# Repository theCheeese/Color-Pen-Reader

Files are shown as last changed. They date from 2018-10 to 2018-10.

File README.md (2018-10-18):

# Color-Pen-Reader
This is an open-source pen reader for dyslexic and visually impaired people that is able to read text written in any color on any colored background, started at NYIT for 2018's Senior Design course.

# Setup

To set this project up, you will have to buy all the parts listed, assemble everything together and make all the right physical connections according to the docs listed in the Final Senior Design Proposal pdf in the Proposals folder.

The software setup is done by first expanding the Raspi filesystem in raspi-config, then removing any extraneous programs the stock Raspi came with like Libreoffice and Wolfram Alpha, and then running the setup script in the ColorPenReader folder. If you have around 5-6 GB free on the SD card though, you can just run the setup script as is and not worry about storage space. The setup script installs all the required dependencies, tesseract-ocr, festival, virtualenv, pip, modifies the .profile file to accomodate the changes, and compiles OpenCV 3.4.1 on the Raspi.

If the setup script encounters issues with compiling OpenCV, refer to https://www.pyimagesearch.com/2017/09/04/raspbian-stretch-install-opencv-3-python-on-your-raspberry-pi/ for a tutorial on how to compile OpenCV by hand.

# Use

Once the setup is complete, you should be able to run the Color Pen Reader (assuming the hardware is set up properly too) by running the startup script. This script executes source ~/.profile, starts the cv Python virtual environment, and runs the main loop of the Color Pen Reader.

To use the Color Pen Reader, the camera must be positioned such that the macro lens is around 1 cm away from the text, then the scanning button is pressed and held down, the scanner is dragged across the text (letting the wheel rotate), and then the button is released to end scanning. The series of images taken is concatenated into one, the resulting image is filtered using edge detection + binarization, and then the filtered image is read by Tesseract, transforming the image into a string, which is then read out by festival.

# Issues

Tesseract is poor at dealing with slanted text. Tesseract OCR seems to depend on machine learning algorithms in order to read text, and it appears that it wasn't trained for this specific purpose. Perhaps there is a way to improve this reliability by training with a new data set?

The output sound is too quiet. Please find or assemble a louder amplifier.

The wheel that measures the distance that the scanner has traveled while scanning is too large. Minimizing it (and overall reworking the 3D printed model of the scanner) and exchanging the current rotary encoder with a more accurate one would go a long way toward improving reliability since this would minimize gaps and overlaps between images and make text more consistent.

Improving the speed of the algorithms used would benefit the project greatly. It seems that the color filter stage is slow at dealing with high-resolution images (or long scans). Improving the time complexity of the algorithms would improve the performance in the greatest way.

The camera's framerate is slow and does not accommodate fast scans. Finding a faster camera might require different hardware than the Raspi, which makes this a complex issue.

If there is a way to switch off most of the OS for when the Color Pen Reader was running (on boot of course), resources would be freed and the performance would be improved.

If there is a way to utilize all four cores in processing the input, the performance would be improved.

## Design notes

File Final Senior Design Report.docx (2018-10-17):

Background

Dyslexia affects 5-10% of the general population, with some estimates going up to 17%.

This has a profound effect on productivity of the labor force, as well as creating economic loss as

tens of thousands of dollars are spent by families to accommodate their dyslexic children.

However, even after their formative years, dyslexic people struggle to hold down a job due to

their disability. Furthermore, about 3.4 million people in the US alone are blind.

One of the best investments any dyslexic person can make for their children is a purchase

of the pen reader. It is a product for dyslexic, visually impaired, or otherwise handicapped people

that reads written text aloud upon scanning text. It utilizes an Optical Character Recognition

engine implemented in software to take raw input from the scanner at the front of the pen and

cleans it up until it recognizes a character of a certain font. The pen reader then compiles words

and sentences out of these characters and outputs and reads them aloud. It can also read aloud the

meanings of certain words so that the user can understand unfamiliar words. It can also translate

between languages. However, the pen reader's limitations include an inability to read colored text

on colored backgrounds. This can get in the way as a lot of jobs depend on reading text whether

or not it is of a different color, or that it is on a colored background.

Our main objective is to explore the use of different filters and image processing

techniques to improve the pen reader's performance in reading colored text on colored

backgrounds, or to design our own pen reader which would be able to read such text.

Statement of the Problem

Current pen readers are very advanced and optimized with their proprietary OCR engines, however, they cannot read text in color, or text on colored backgrounds. This is a problem because a lot of work is done with text that isn’t simply black text on white background. For example, a supermarket needs workers to sort out their inventory and determine which items are on sale. Items that are sold in these stores are almost never simply black text on white backgrounds, but may be colored or stylized. People with reading difficulties and visual difficulties are then effectively barred from working these jobs.

Rationale

The fundamental reasons behind the hardware are thus:

The Raspberry Pi 3B was chosen because it is a small computer with the most resources, processing power, and documentation available.

The speaker amplifier and speaker were chosen to make the text audible as well as keep the size small enough to have the ability to attach directly to the Raspberry Pi

The battery was chosen to match the size of the Raspberry Pi, as well as provide a large reservoir of energy to be able to use the color pen reader for a long time. The estimated battery life of the color pen reader is 5 hours at minimum (with constant scanning).

The Raspberry Pi Camera Module V2 was used to capture the images. It is the only camera module that is compatible with the Raspberry Pi by default. Other cameras can be used but due to time constraints we were not able to test different cameras with the color pen reader.

The Trinket M0 was primarily chosen for its small size and powerful chip. It is also phenomenally easy to program. A microcontroller in general was used because they are better at handling realtime inputs, outputs, and operations.

Design

The design of the color pen reader was chosen to be simple and minimalist to satisfy time constraints and to have as much time to refine each component as possible. The design is detailed in the block diagrams on the USB. First, the camera controller runs and takes visual input from the page being scanned and input from our feedback system. Upon encountering the signal that the user is scanning and the signal that a picture of the text should be captured, the camera controller sends the command to capture the current image and save it in the rawImages directory. It repeats this until the user stops scanning. The feedback system uses a button to tell when the user is scanning text and a rotary encoder to measure the distance that the color pen reader has traversed, and sends a voltage impulse whenever a certain distance (about a centimeter in our case). The set of images then goes into an image stitcher that combines the images into one single image. This then goes into the color filter stage, which detects the edges of the text image. Then, it scans each letter for its type and figures out whether the current character has no holes (like an L), one hole (like an O), or two holes (like a B). Every letter in the English language is one of these types. It then fills in the text with black color. Then the image goes into Tesseract to convert into a string of text and is read out by festival, a text-to-speech converter. Tesseract and festival were installed so that we didn’t have to implement our own OCR engine and text-to-speech converters (a much too difficult task for our available resources and time constraints).

Development

Development started with a meeting with AHRC and an actual user of current pen reader technology. We then determined the requirements of our project, which was originally to design a modular attachment for an existing pen reader and to use a robot arm to make it autonomously sort objects by label. We proceeded with research on how to filter out the colors from a text image. We tried various methods of edge detection like Sobel filtering, making a filter that utilizes the cosine similarity theorem, and a Canny edge detector. We determined that the Canny filter worked best of all. We then started to work on how to fill the text in with black color. At the same time we also contacted the company that manufactures the pen reader we were modifying and found that it was impossible to make any attachments. With this new information our team decided to design its own color pen reader from scratch using open-source components.

We first drew up the high level design of the color pen reader. Once we were satisfied with the design we proceeded to determine the requirements of each component that we planned out. After determining this we started implementing each component backwards; that is, from the final stage that gives the user the output to the input stages. We chose to do this because the color filter was already half finished and we successfully tested the Tesseract OCR engine together with a text-to-speech converter called festival. Not only that, but the inputs to the already-finished components were already well-defined. Working backwards thus made development faster.

After creating the color filter and implementing festival and Tesseract, we implemented the image stitcher quickly and started work on the feedback and the camera controller. The feedback was developed first because that determines the inputs to the camera controller. Just after finishing the code for the feedback, it was already a couple of weeks before the CREATE symposium. So, we paused the main development and instead focused on building the first prototype to show at the symposium. For this we also quickly designed a simple 3D printed scanner and attached all the hardware necessary to make it portable (the battery, amplifier, speaker, button, and camera). This first prototype could take a single image, filter out the color successfully, and speak what was on the image. After the symposium we finished the feedback and the camera controller and assembled the final prototype in order to enable the color pen reader to read lines of text in multiple images instead of just one at a time. A new 3D printed enclosure and wheel were also designed to house the feedback system as well. We assembled the final prototype, tested it, determined the issues that should be resolved afterwards, and presented it at our final presentation.

Evaluation

The color pen reader has limited functionality, with some major issues to be resolved. The main issues, as outlined in the demonstration video, include a latency between the feedback system sending the signal to capture an image of the text and the camera actually capturing the image. Not only that, but the latency almost seems to vary. This can be resolved by using different hardware or by using an algorithm that is faster at capturing images, perhaps using two threads running on two of the Raspberry Pi’s available four cores (one for capturing the image and saving it to a buffer and another thread for writing the buffer into an image file). This should remove any variation between the latencies, and once they are equal, the images taken can be cropped according to where an overlap between the images exists. This would clean up the input to the processes that process the input images into sound.

Another major issue is that the Tesseract OCR engine in its out-of-the-box form does not read text at any angle. If the text is not completely horizontal, Tesseract will think it’s looking at an empty page. This can potentially be resolved by training Tesseract with a database of images (since it is based on a neural network). This should resolve any reliability issues assuming the user doesn’t scan the text in a wavy motion.

The speaker that outputs the generated speech is quiet. This can be rectified by selecting a different sound amplifier to use with the color pen reader. The speakers may also be changed in case they are not as efficient as they can be.

There are issues with focus in capturing images. Due to the nature of using a camera to capture images instead of something like a linear CCD sensor, the camera needs to be at the correct distance away from the text in order for the image processing to take place correctly. We have placed the wheel of the scanner at approximately the correct distance away, but there are issues when the color pen reader is not vertical. This can potentially be corrected by either using a different sensor altogether to capture images of the text or by adjusting the parameters of the color filter (in the edge detection portion). There can also be an LED light that tells the user when the camera is in focus (by affixing a realtime edge detector to the camera controller and finding a maximum in the edge detector’s output, which controls the brightness of the LED).

These issues must be fixed by future developers if the color pen reader is to be reliable enough for practical use.

Discussion

The color pen reader is able to filter out any colored text on any colored background. Our design is such that in theory it should be able to even filter out multicolored text. However, there is still room for improvement.

The color pen reader can be made more efficient in software in the processing required. We have tried to minimize processing time but due to time constraints, there should be room for improvement. A more efficient algorithm means a less powerful computer is required to contain the color pen reader. This can be a Raspberry Pi Zero, and owing to its small size, it is less power-hungry. This means a smaller battery can be used and the color pen reader’s size can be optimized into a single handheld device.

The color pen reader is designed to be modular, so more stages can be added in between different stages, and therefore it can be expanded upon. There can be a dictionary or a translator function built in between the Tesseract stage and the text-to-speech stage, so that language barriers can be lifted along with reading difficulty barriers.

References

Siegel, Linda S. “Perspectives on Dyslexia.”, Paediatrics & Child Health 11.9 (2006):

581–587. Print.

Bailey R. N., Indian R. W., Zhang X., Geiss L. S., Duenas M.R., Saaddine J. B. “Visual

impairment and eye care among older adults—five states,” MMWR 2006; 55(49):1321–1325.

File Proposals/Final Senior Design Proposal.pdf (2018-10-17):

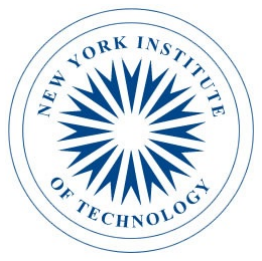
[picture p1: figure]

# Color Pen Reader

By Team Tao

Oluwadarasimi Adeniyi (Dara)

Haoran Wu (Steven)

Michael Syrov (Michael Mordkovich)

Kaixian Zhu (Ellis)

Faculty Advisor: Dr. Anand Santhanakrishnan

Capstone project proposal submitted in partial fulfillment of

the requirement of the Degree of Bachelors of Science

in the Department of Electrical and Computer Engineering

in the School of Engineering and Computing Sciences

of New York Institute of Technology

Spring 2018

## Table of Contents

## Abstract

Dyslexia affects 5-10% of the general population, with some estimates going up to 17%.

This has a profound effect on productivity of the labor force, as well as creating economic loss as

tens of thousands of dollars are spent by families to accommodate their dyslexic children.

However, even after their formative years, dyslexic people struggle to hold down a job due to

their disability. Furthermore, about 3.4 million people in the US alone are blind.

One of the best investments any dyslexic person can make for their children is a purchase

of the pen reader. It is a product for dyslexic, visually impaired, or otherwise handicapped people

that reads written text aloud upon scanning text. It utilizes an Optical Character Recognition

engine implemented in software to take raw input from the scanner at the front of the pen and

cleans it up until it recognizes a character of a certain font. The pen reader then compiles words

and sentences out of these characters and outputs and reads them aloud. It can also read aloud the

meanings of certain words so that the user can understand unfamiliar words. It can also translate

between languages. However, the pen reader's limitations include an inability to read colored text

on colored backgrounds. This can get in the way as a lot of jobs depend on reading text whether

or not it is of a different color, or that it is on a colored background.

Our main objective is to explore the use of different filters and image processing

techniques to improve the pen reader's performance in reading colored text on colored

backgrounds, or to design our own pen reader which would be able to read such text.

### 1. Executive Summary

The problem we would like to address is the inability of the pen reader to recognize

colored text on a colored background. A pen reader is a device that scans lines of text and uses

Optical Character Recognition (OCR) technology [3][8] to recognize words and read them out

loud to the user. Currently, there are some pen readers with limited color reading ability, but they

fail reliably on certain colors and certain backgrounds due to their limitations. We have explored

the possibility of the creation of a modular attachment or a modification to the commercially

available pen reader that can enable the pen to read text no matter what the color is, and found it

was impossible. Therefore, we have designed our own pen reader that can take colored input. To

do this, we designed a filter module in software using a Raspberry Pi computer to make colored

text input readable to available open-source software like Tesseract and festival.

### 2. Opportunity

Our project will help handicapped people by letting them read more text they cannot

otherwise read. Around 5-10%, with some estimates going as far as 17%, of the general

population of the US is dyslexic[1]. Around 3.4 million people in the US are legally blind[2].

There aren't very many things that are written in black text on a white background except for

new books and special labels. Many things, such as product packaging, old yellowed books,

logos, and others have their text stylized in a special font or color or printed on a unique

background. The pen reader on its own is designed to take different fonts into account, but the

problem is that it cannot read color, and so these people have more trouble getting through their

workday than the average worker does. By creating a new pen reader that can filter out color in

text, we can lift that barrier to dyslexic, blind, or workers with other reading disabilities and

allow them to work in jobs previously unavailable to them. Any job where you have to sort

things by label or involves other form of text (package sorter, warehouse worker, etc) is filled

with this kind of work. Dyslexic students and researchers would also benefit from this

technology by making it easier to study from old, yellowing books. It will also help those with

disabilities with navigation. There is also an opportunity to reduce the amount of money spent on

special education for dyslexic people, as well as an opportunity to reduce the amount of stress

these workers experience, improving their productivity.

### 3. Proposed Plan of Action

### 3.1. Project Components

We have designed a new open-source pen reader with an image processor that filters out

the raw information from the pen reader's scanner and transforms it into a form that is acceptable

for the pen reader to process. The image processing occurs on a Raspberry Pi while scanning

takes place with both a Raspberry Pi and a Trinket M0 microprocessor working in tandem. We

have attempted to create a modular attachment but found it was impossible after doing more

research and contacting the company that manufactures the pen we have studied. The robotic arm

portion of the project has been cancelled due to these changes in the project requirements.

We achieve this by first scanning the text with a Raspberry Pi camera and combining the

set of input images. We then apply a Gaussian filter to the input first to mitigate noise. After the

Gaussian filter stage, we use a differential filter (edge detector) in software in order to sense

sharp changes in color and intensity between pixels and create a black and white image based on

that. This will create an outline of the text scanned. We have further added a post-processor to

the system that detects letters and detects the kind of letter it is (with no holes like an L, with one

hole like an O, or with two holes like a B) and fills those edges in with black color so the pen

reader is able to process it. Processing of the filtered text is performed by Tesseract, an open-

source OCR engine and the output speech is created by festival, an open-source text-to-speech

converter.

We started with a high level design of the hardware and software and determined the

inputs, outputs, and the requirements of each part in the project. After this, we continued to refine

each high-level part into a series of low level requirements and designs in somewhat of a waterfall approach. One of the main components in the open-source pen reader's design is the

OCR engine and the text to speech software. Open-source software exists for both of these – we

have chosen Tesseract for the OCR engine and festival for the text to speech conversion because

Tesseract is the best open-source OCR engine available currently and festival does its job well.

Because these components have well-defined outputs and inputs, and since the output of festival

is the only required output of our pen reader, we have chosen to pursue the refinement of the

design backwards; that is, we have decided to design and implement the pen reader from the

output to the input.

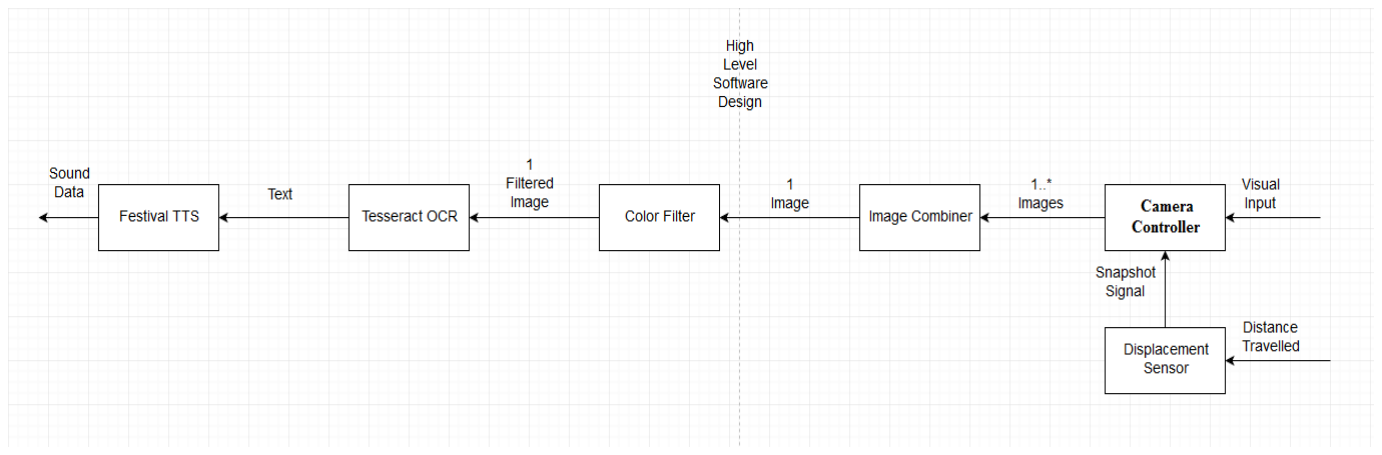
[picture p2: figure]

Figure 1: High-level Software Design

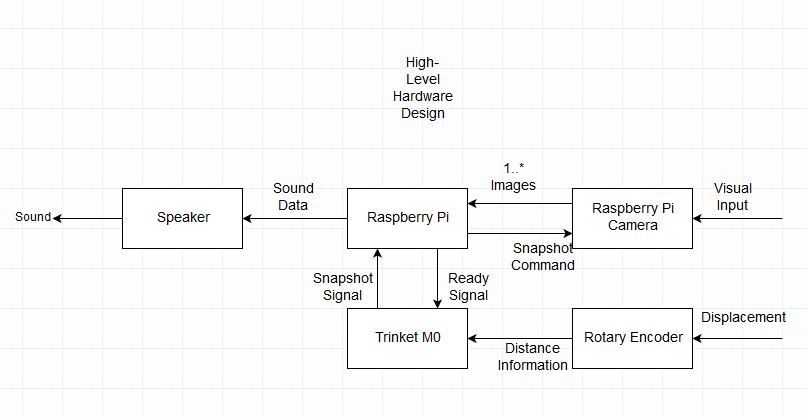
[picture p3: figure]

Figure 2: High-level Hardware Design

The camera is controlled by Raspberry Pi, which listens to two signals isScanning and

CaptureInterrupt sent by microprocessor Trinket M0. When isScanning signal is low, the camera

module is off-work and when isScanning signal is high, the camera will take one photo every

time the captureInterrupt signal’s rising edge comes. The camera will go back to off-work mode

when isScanning signal goes back to low from high and the next stage will execute.

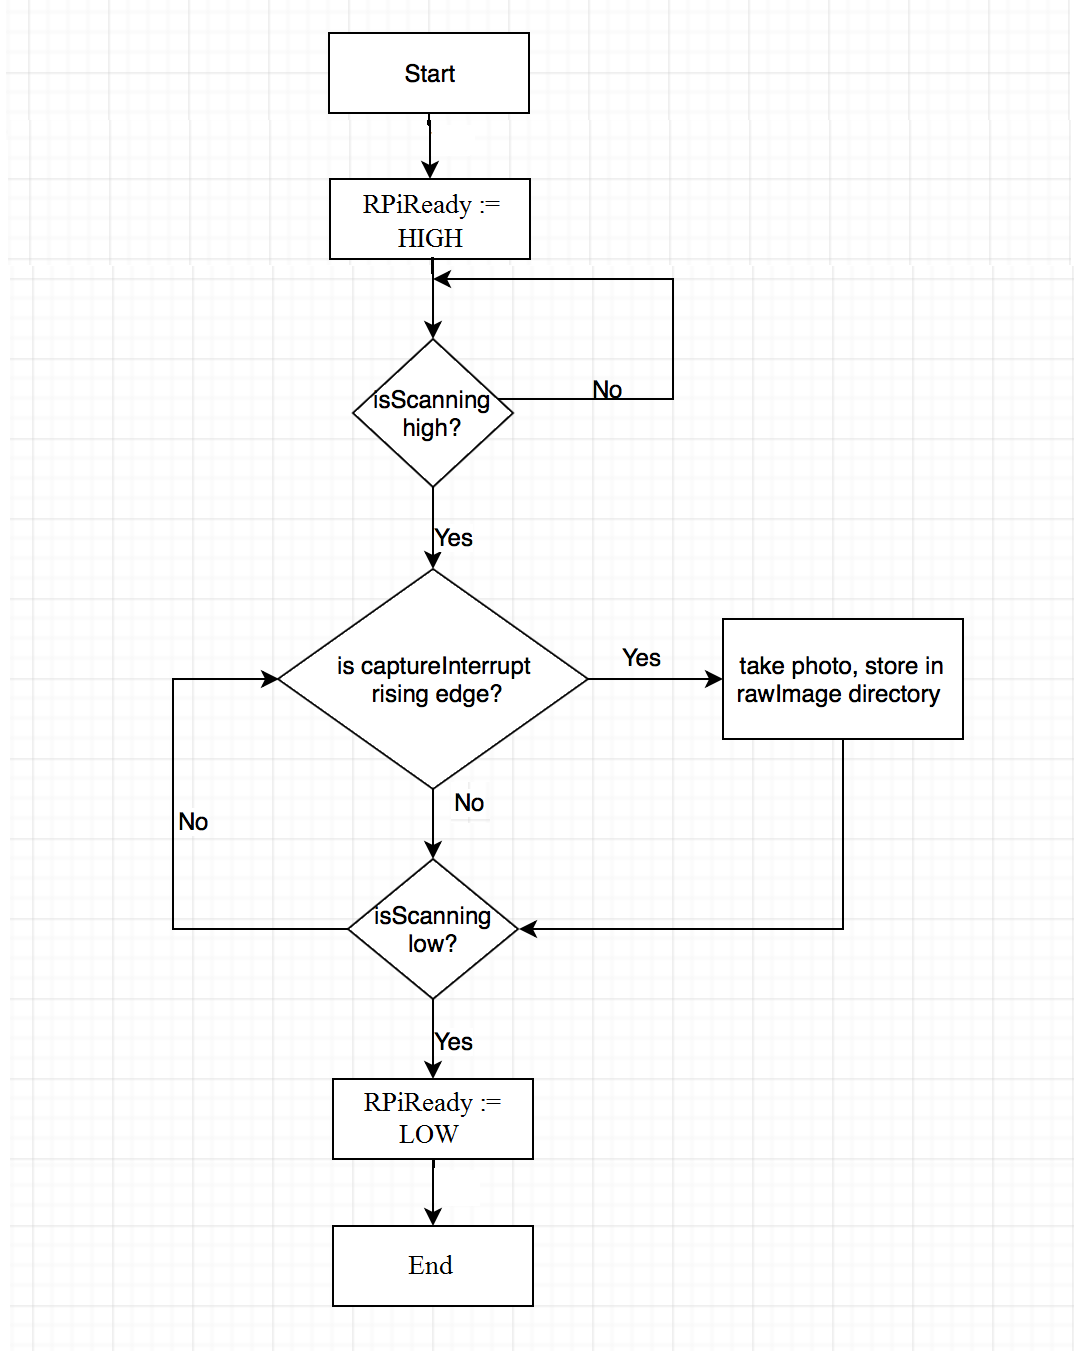
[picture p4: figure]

Figure 3: Camera Controller Design

The camera controller depends on feedback from our closed-loop feedback component of

the project. A Trinket M0 in combination with a rotary encoder measures the distance travelled

by the pen reader while scanning text and outputs a captureInterrupt pulse to the Raspberry Pi.

This tells the Raspberry Pi to take a snapshot of what the camera is currently looking at. This is

to keep images evenly spaced so future concatenation will result in the entire text being without

gaps or repetition (from intersecting images). Since it depends on distance travelled, it also lets

the system account for variations in the user's scanning speed. There is a limitation, of course.

Too fast of a scanning speed with result in image blurring and a detrimental effect on the output.

The closed-loop feedback waits until the camera controller module is running so it does not

waste power while the pen reader is processing text. Then, when the Raspberry Pi is ready for

input, it waits until the user holds a button which tells the Raspberry Pi that the user is currently

scanning. It then reads the encoder for changes in position and outputs a captureInterrupt pulse

for the Raspberry Pi to take a picture. When the button is released, it tells the Raspberry Pi that

scanning is finished and the pen reader moves on to concatenate the images and process the

input.

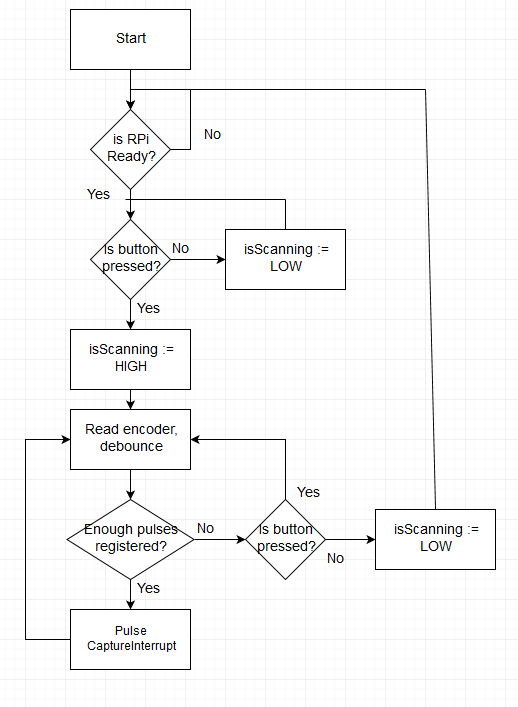
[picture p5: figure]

Figure 4: Closed-loop Feedback Design

The image combiner module loads all the images that have been taken by the camera

from one scan and combines them into one single image by concatenating them all.

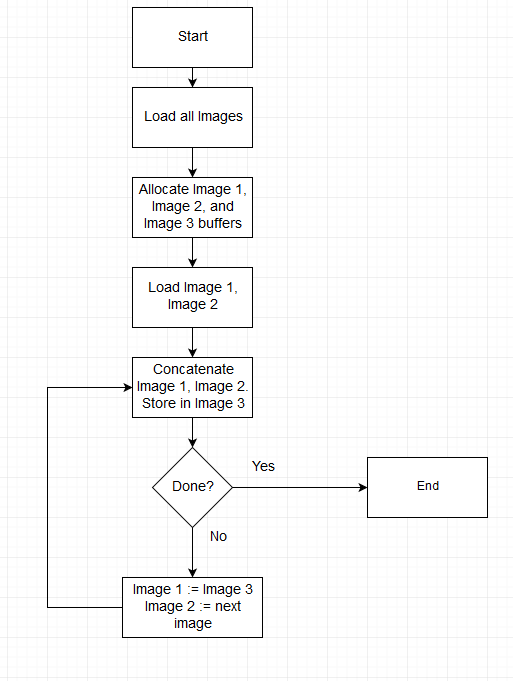
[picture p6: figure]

Figure 5: Image Combiner Design

The color filter component was designed starting from edge detection. Usual methods to

detect edges include Canny edge detection [4], image derivative (Sobel Filter) [5], and phase

stretch transform [6]. The first two are available in software libraries like OpenCV which we also

plan to use. The last is not; however, that capability has been open-sourced. We have also

explored the possibility of using the cosine similarity method [7] to produce edge detection by

putting the color and lightness data of a pixel into a vector and comparing two adjacent pixels. A

value close to 1 indicates similarity, and thus no change in color, while a value close to 0

indicates difference, and thus a change in color. This method is not available to implement in

OpenCV by default, but is fast and easy to implement. This method has also been used before,

albeit not as commonly as the others mentioned, but it was stumbled upon independently by the

group and has potential. After experimentation with MATLAB simulations we have decided that

Canny Edge Detection works best. Our experimentation with Tesseract showed that edge

detection is not enough to reliably read text from images, and that post-processing would need to

be performed. This was included in the color filter module. After the differential filtering is

performed, the color filter binarizes the image and detects separate letters and their type

(specifically, whether the letter has no holes like an L, one hole like an O, or two holes like a B).

After determining the type of letter, it fills in the text accordingly.

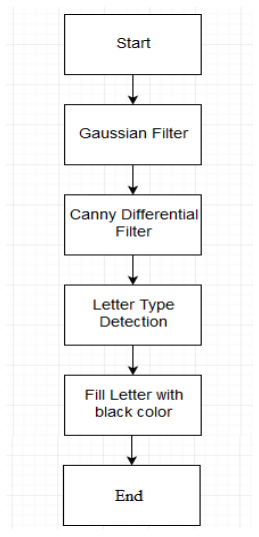
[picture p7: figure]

Figure 6: Color Filter Design

After processing the input image, it is fed into the Tesseract OCR engine, which converts

the image into text. The output text of Tesseract is then piped into festival which converts it into

sound data. This is sent to the speaker for reading aloud.

### 3.2. Hardware/software Requirements

1. Raspberry Pi 3

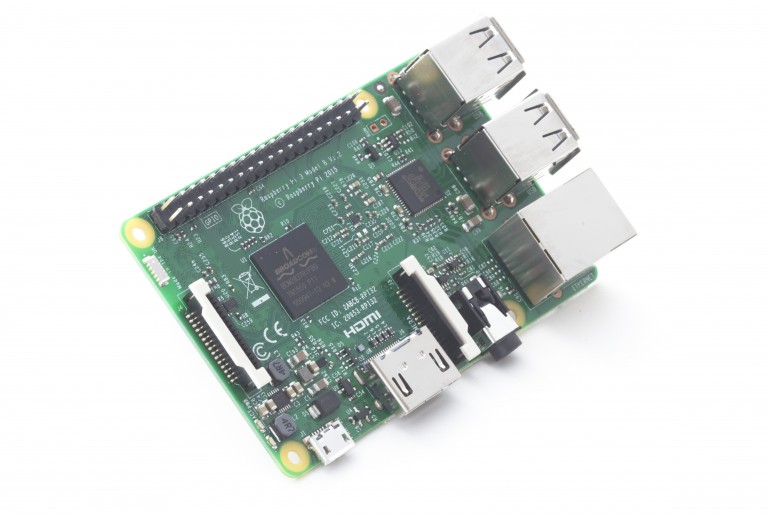
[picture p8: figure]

Figure 7: Raspberry Pi 3

The Raspberry Pi 3 will serve as the main processing module of our project. It will

receive the feedback from microprocessor Trinket M0 and then control the camera module to

take photos. The Raspberry Pi 3 will also process the photos taken by camera, filter out the color

and send black-and-white image to Tesseract OCR engine and festival text-to-speech software.

2. Microprocessor Trinket M0

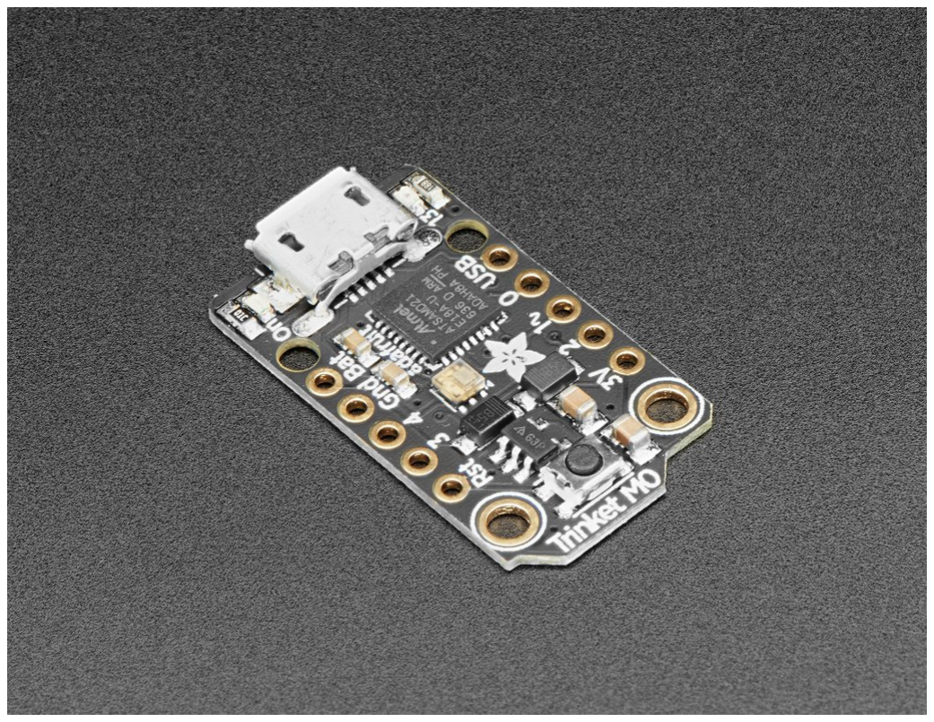
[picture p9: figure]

Figure 8: Adafruit Trinket M0

This microprocessor Trinket M0 sends two signals isScanning and captureInterrupt to

the Raspberry Pi and it receives the pulse sent by rotary encoder and signal from a button. If the

button is pressed then the Trinket M0 will set the signal isScanning to high and calculate the

distance between position of camera module and the next position of camera module based on

the length of the received pulse’s high level. If the distance reaches a threshold value set in the

code, then the Trinket M0 will set the signal captureInterrupt to high.

3. Raspberry Pi Camera Module

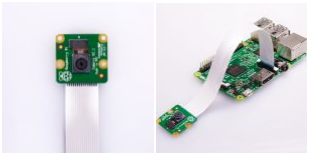
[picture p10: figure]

Figure 9: Raspberry Pi Camera Module V2

This camera module V2 uses Sony IMX219 sensor and it’s resolution can reach up to

3280 x 2464 pixels. It will take the pictures of the text to be processed. If processing is slow, the

resolution can be reduced.

4. Rotary Encoder

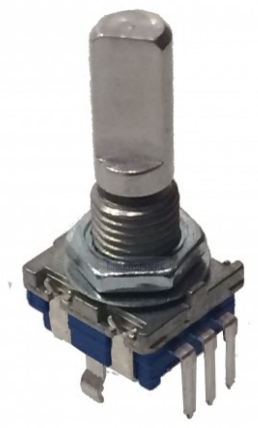
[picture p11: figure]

Figure 10: 20p/r Incremental Rotary Encoder

We adhere a wheel to its shaft and use it to measure the distance the pen reader has

traveled. When the wheel rolls on the surface of reading materials, the encoder will send out

pulse to microprocessor Trinket M0, then the distance will be calculated and sent to the

Raspberry Pi.

5. Audio Amplifier

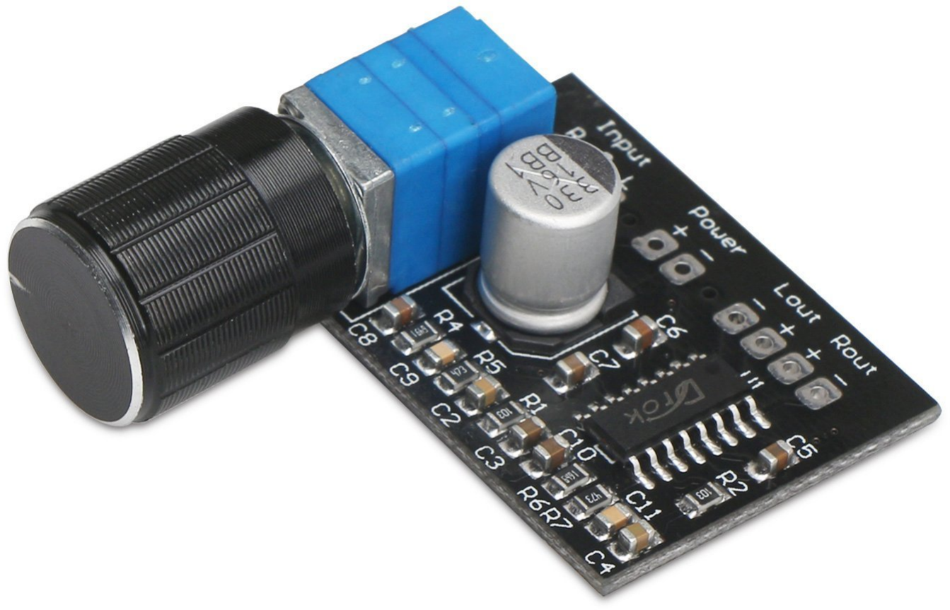
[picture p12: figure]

Figure 11: Drok 3 Watt Sound Amplifier

This is connected to the Raspberry Pi's 3.5 mm jack in order to amplify the output of the

color pen reader to audible levels.

6. Speaker

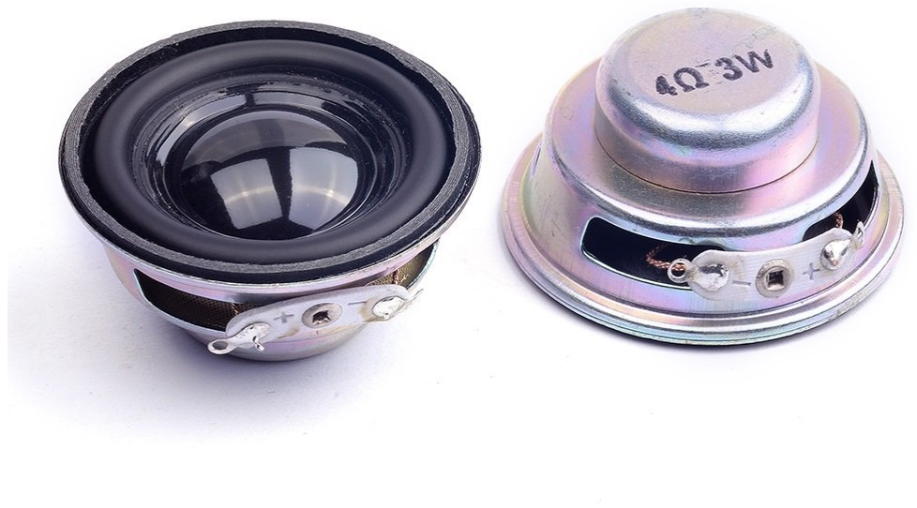
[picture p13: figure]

Figure 12: Cylewet 4 Ohm 3 Watt Speaker

This is a speaker that outputs the final output of our color pen reader.

7. Battery

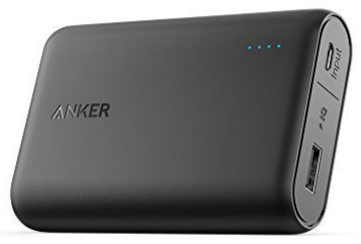
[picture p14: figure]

Figure 13: Anker Powercore 10000 mAh Li-Ion Battery

This is the battery used to power the color pen reader. With 10 Ah of capacity, it allows

the color pen reader to continuously and actively operate for up to 5 hours, with a more realistic

estimate being around 8 hours.

### 4. Commercialization

We have to introduce the rational benefit on our improved reading pen. Our tech makes

the reading pen different. When you scan light color characters with darker background, ordinary

reading pens can’t recognize any words at all, which means that handicapped people will have a

harder time reading, and you still have to struggle on looking up words one by one via cell phone

or dictionary. Our project removes the pen reader's color limitation, so you can scan any color of

words conveniently as long as there’s a color difference between characters and the background.

Our project will target people with reading difficulties such as dyslexia, which is a real

time saver to them. Also, those who suffer from the limitation of original reading pens are

willing to see our breakthrough that we remove the color limitation.

We should let customers unconsciously accept the concept of improved reading pen. We

will plan and implement BTL marketing activities which will include free improved pen

experiencing, comparison between the old one and the improved one, distribution of brochures

or banners to introduce feature of our product, scanning QR code to let them feel free to follow

our social media account which helps us to push further notifications. Once their feedbacks are

received through these activities, it will be more efficient to satisfy their needs and leave a good

impression.

We’ll meet a lot of new problems in commercialization. As we all know, there are too

many interconnections between the commercialization and the business operations. However, it

seems that we are neither experienced enough in business operations nor do we have enough

money to commercialize alone. What’s more, our improvement is an integral part of the reading pen. It would be wise if we can cooperate with a reading pen company as we share mutual

interest. They own the marketing and have more experience in business operations. Also, we can

provide more convenient tech to improve their products, making the cooperation viable. How to

maximize the market acceptance is another thing need to take into consideration. We have to

admit that it’s not an indispensable tool for everyone. It is a specialized product designed for

specific people in mind. It cannot be immediately accessed as a platform like a phone app, which

means that improved reading pen cannot be spread as easily. In order to speed up the formation

of this marketing, we should not only focus on people who have issues on reading but try to

create an ambience to people whose English is poor and don’t want to look up words one by one

on cell phones and dictionaries. We must convince them that it would be a better choice to use

our improved reading pen to fix this issue. Through this guidance, they will remember our

product and realize how convenient it is, then gradually accept it.

Commercialization of the reading pen does not keep it from being open-sourced; instead,

commercialization will help the reading pen become known and will attract more developers to

improve it in the future. We have therefore open-sourced the design and the repository containing

the software, the proposal, and the hardware connections are available on Github at

Comrade96/color-pen-reader.

### 5. Limitations and further Development:

1. OCR technology’s limitation

Optical character recognition technology which is used in our pen has its limitation in

recognizing several parallel character lines. For instance, if the scanner of the pen

includes two lines or one line of characters plus portion of other lines in one scanning,

then the pen cannot recognize two lines or one specific line. We need to improve this

either by restricting the scanning area from outside or improving the algorithm inside the

pen. Not only that, but even modern reading pens' success rates range from 81% - 99%

[9].

2. Pen’s limitation

What hardware design the existing pen use in scanning port is same as barcode reader.

The pen emits light to a surface which is scanned by the user, then the pen receives the

reflection of light and process this reflection. We must use a pen that emits only white

light to illuminate the text, otherwise the pen cannot scan colorful materials because

reflection of colored light on same-colored text would be the same color, however if the

background was white, the same color would be reflected too, giving no contrast between

text and background. This means if we want to scan colorful materials, the pen needs to

emit white color which can reflect any color.

3. Recognition algorithm’s limitation

The precision of character recognition algorithm in existing pen is not very high. When

we use the pen in scanning some hand-written characters or noisy text, it cannot

recognize them precisely, if at all.

4. Our scanning module’s limitation

If the contrast between text and background is small, the edge detector output will be

faint. This will make it hard to fill in the edges by the post-processor in the next stage. We

may combine different methods for edge detection and use the output of that, but that

may slow the process down. We must find a good balance between filter quality and

speed.

### 5.1. Impact

1. Our reading pen can help people with dyslexics.

It is estimated that 1 in 10 people have dyslexia [1]. Over 40 million American Adults are

dyslexic - and only 2 million know it. These people cannot read materials as efficient as

people who do not have dyslexia. Our reading pen can help these people solve this

problem because our pen can display, can read in high speed and in high accuracy.

2. Our reading pen can help people who are visually impaired.

Our reading pen can read what it scans so that it can help people who are visually

impaired to understand reading materials. By listening to reading pen, people who have

disability in eyesight can easily understand materials in a normal speed.

3. People who are not familiar with English can also use this pen to help them work.

With our modified algorithm, the reading pen can scan and translate reading materials in

a high speed and high accuracy. Then, people who do not understand English can

understand English as fast as people who are familiar with English.

When our project is successfully finished, it would make life easier for disabled

people, it would improve reading experience and it would make getting jobs easier for

disabled people.

### 5.2. Prior Art

There are many competing technologies like the C-PEN Reader, ScanMarker and Power

Pen but they don’t read colored text on colored backgrounds well. We have resolved this limita-

tion.

Open-source software for OCR such as Tesseract (and others) exist and are freely avail-

able. Of open-source technologies, Tesseract is the most accurate and will be used for our pur-

poses. Proprietary OCR engines offer higher accuracy in reading text from images, but are not

available to us due to our goal to make the pen reader open-source.

Festival is an open-source software tool for converting text to sound data. It is one of the

best available in terms of voice clarity. We have also used this to develop our project.

### 6. Project Management Plan

### 6.1. Potential Future Improvements

The color pen reader in its current form is not without its limitations. There are notable

reliability limitations owing to the color filter's parameters not being totally optimized. As such,

it sometimes gives wrong results. There is also the limitation stemming from the fact that it is of

a large size that is though handheld and portable, still is quite large and consists of two separate

components. Other limitations exist such as the OCR engine not being able to accurately read the

text from the image from time to time. There is also the fact that the output is a little quiet due to

the speakers not being loud enough, or the amplifier not being as powerful as advertised.

Some of these limitations can be rectified, however. In the future, by finding better

parameters for the color filter, the accuracy and reliability of the color pen reader can be

improved. The color pen reader can be made smaller by using a Raspberry Pi Zero or a smaller

computer to implement the software, as well as use a smaller speaker, a smaller battery, and a

more powerful amplifier to facilitate its function. This can potentially reduce the color pen

reader's size to a single component, and possibly even pocket-size it, which would be ideal.

### 6.2. Team and Collaboration

Michael Syrov (Project Manager/Hardware/Software Engineer)- A very experienced

engineer who has managed several projects, he is well spoken and very organized. He has

also worked with OCR technology and has a clear idea of the direction in which the

project should go. He will be responsible for making sure the project is delivered on time,

within scope and within budget.

Haoran Wu (Hardware / Software Engineer)- Haoran has worked on different projects

which required use of Field – Programmable Gate Arrays (FPGA) and microprocessors.

This experience will be useful in our project.

Ellis Zhu (Software engineer)- He has had a lot of internship experience which has

prepared him for this project. He is a great programmer, very good with Python and

excellent at programming with a Raspberry Pi. He has prior knowledge in modifying

existing codes from OpenCV and writing a code from scratch and is willing to do more

research.

Oluwadarasimi Adeniyi (Project Manager/ Researcher)- Has previous management

experience, led a 5 person team in previous school projects, worked as a general manager

intern, and is also a good researcher and finds useful technical detailed information about

the project. He will be responsible for gathering useful documents, finding reliable

sources and making sure the project is delivered on time.

### 6.3. Milestones and Timeline

Task | Date
Initial Research | 10/07/17 – 12/03/17
AHRC Meeting | 10/24/17 – 10/25/17
Project Proposal Presentation | 11/14/17 – 11/15/17
Budget Acquirement | 11/21/17 – 11/21/17
Pen Reader Acquirement | 11/22/17 – 11/25/17
Decision on Main Approach to Solution | 12/03/17 – 12/25/17
Materials Acquisition | 12/20/17 – 1/17/18
Implement Color Filter | 1/17/18 – 3/1/18
Implement Image Combiner | 1/25/18 – 2/3/18
Prototype 1 | 4/3/18
Prototype Tweaking/Prototype 2 | 4/3/18 – 5/10/18
Final Report | 5/9/18

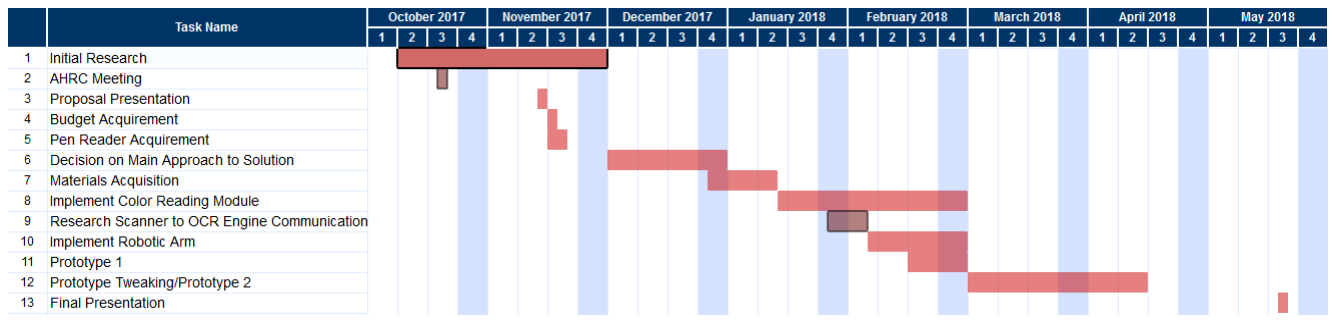
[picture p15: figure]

Figure 11: Development Schedule

### 7. Use of Standards

We have not found any use for standards in this project. The Bluetooth standard would

have been used, but the robotic arm part of the project had been cancelled.

### 8. Resources and Budget

Item | Unit Price | Units | Purpose | Link
C-Pen Reader | $250 | 1 | This is the Pen Reader we plan on expanding. | https://www.amazon.com/C-pen-C-Pen-Reader/dp/B015O L7VNS
Raspberry Pi 3 Kit for develop-ment | $69.99 | 1 | It would greatly expediate development if we have a Raspberry Pi dedicated solely as a development platform so that we wouldn't have to swap Pis in and out of our project to try some new code. | https://www.amazon.com/CanaKit-Raspberry-Complete-Starter-Kit/dp/B01C6Q2 GSY
Raspberry Pi 3 for prototype | $35.05 | 2 | One for the Color Reading Module and one for the Robot Arm | https://www.amazon.com/Raspberry -Pi-RASPBERRYPI3 -MODB-1GB-Model-Motherboard/dp/B 01CD5VC92
Raspberry Pi Camera Module | $28.31 | 1 | This will be used to replace the original scanner sensor of the pen. | https://www.amazon.com/Raspberry -Pi-Camera-Module-Megapixel/dp/B01 ER2SKFS/

Lynxm otion AL5D 4DOF Robotic Arm SSC-32U Combo Kit | $350.80 | 1 | This is the Robot Arm hardware to be controlled by one of our Raspberry Pis. | https://www.robotshop.com/en/lynx motion-al5df-kt-robotic-arm-flowbotics-studio.html
IC3D PLA 3D Printer Filament | $29.99 | 1 | We would like to print an enclosure for the Color Reading Module to defend against accidental dropping and other damage. | https://www.amazon.com/IC3D-White-1-75mm-Printer-Filament/dp/B011 RXNIXO
Turnigy 7.4 V 1000 mAH LiPo Battery | $14.99 | 2 | This will power the Raspberry Pi on the Color Reading Module as well as the one on the Robot Arm | https://www.amazon.com/Turnigy-1000mAh-Lipo-HobbyKing-Battery/dp/B0072 AEHIC
Iusun Mini-360 DC-DC Buck Converter Step Down Module | $0.69 | 10 | This is used to step down the voltage of the LiPo battery to a safe voltage that the Raspberry Pis can handle. | https://www.amazon.com/Iusun-Mini-360-Converter-Mini360-4-75V-23V/dp/B074SK9 SSL

Elegoo HC-SR04 Ultraso nic Module Distanc e Sensor | $11.49 | 1 | This will provide negative feedback to the Robot Arm while it is positioning itself to pick up an object. | https://www.amazon.com/Elegoo-HC-SR04-Ultrasonic-Distance-MEGA2560/dp/B 01COSN7O6
Icstatio n RFP602 500g to 10kg Resistiv e Thin Film Pressur e Sensor Force Sensing Resistor | $10.48 | 2 | This will provide negative feedback to the Robot Arm while it is closing its gripping arm in order keep the arm from crushing the object. It will also sense when the object encounters resistance to movement, signifying that the place the Robot Arm is trying to place the object in is occupied. | https://www.amazon.com/Icstation-RFP602-Resistive-Film-Sensor/dp/B06ZY JRN8M
Bluetoo th 4.0 USB Module | $11.95 | 2 | This will be used so the Color Module and the Robot Arm Control Software can communicate with each other. | https://www.amazon.com/Bluetooth -802-15-1-Modules-Dongle-single/dp/B00HKI LG1W
Fluke 113 True-RMS Utility Multim eter | $97.49 | 1 | Multimeter for testing various parts and ensuring the buck converters are set up correctly. | https://www.amazon.com/Fluke-113-True-RMS-Utility-Multimeter/dp/B0 1EWFE6XK

Total: $989.91
Note: We have $1000 of funding from AHRC already approved.

## References

[1] Siegel, Linda S. “Perspectives on Dyslexia.”, Paediatrics & Child Health 11.9 (2006):

581–587. Print.

[2] Bailey R. N., Indian R. W., Zhang X., Geiss L. S., Duenas M.R., Saaddine J. B. “Visual

impairment and eye care among older adults—five states,” MMWR 2006; 55(49):1321–1325.

[3] Eikvil, Line. "OCR-Optical Character Recognition.", 1993.
[4] Canny, John. “A Computational Approach to Edge Detection,” IEEE Transactions on

Pattern Analysis and Machine Intelligence, Vol.PAMI-8, No.6, November 1986.

[5] Rebecca Vincent, Folorunso O. “A Descriptive Algorithm for Sobel Edge Detection.”

Proceedings of Informing Science & IT Education Conference (InSITE). 2009.

[6] Mohammad H. Asghari, Bahram Jalali. “Edge Detection in Digital Images Using

Dispersive Phase Stretch Transform.” International Journal of Biomedical Imaging Volume 2015.

2015.

[7] Shweta Atul Page, Kavita J. Mahajan. “Edge Detection Based Classification of

Leukocytes in Blood.” International Journal of Computer Science and Mobile Computing , Vol.

5, Issue. 7,July 2016, pg. 353 – 358. July 2016.

[8] Chentung R. Jih. “Optical Character Recognition Using Baseline Information.”,

US4251799 A, Feb 17, 1981.

[9] Holley, Rose. "How Good Can It Get? Analysing and Improving OCR Accuracy in Large

Scale Historic Newspaper Digitisation Programs", D-Lib Magazine, April 2009.

## Appendix

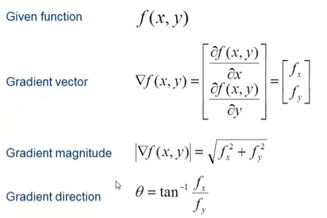
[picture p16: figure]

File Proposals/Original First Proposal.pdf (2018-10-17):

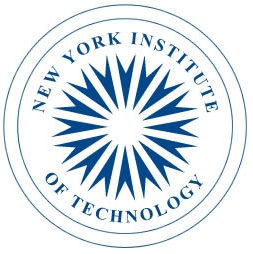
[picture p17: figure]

# Autonomous Color Pen Reader

By Team Tao

Oluwadarasimi Adeniyi (Dara)

Haoran Wu (Steven)

Michael Mordkovich (Misha Syrov)

Kaixian Zhu (Ellis)

Faculty Advisor: Dr. Anand Santhanakrishnan

Capstone project proposal submitted in partial fulfillment of

the requirement of the Degree of Bachelors of Science

in the Department of Electrical and Computer Engineering

in the School of Engineering and Computing Sciences

of New York Institute of Technology

Fall 2017

## Table of Contents

## Abstract

Dyslexia affects 5-10% of the general population, with some estimates going up to 17%.

This has a profound effect on productivity of the labor force, as well as creating economic loss as

tens of thousands of dollars are spent by families to accommodate their dyslexic children.

However, even after their formative years, dyslexic people struggle to hold down a job due to

their disability. Furthermore, about 3.4 million people in the US alone are blind.

One of the best investments any dyslexic person can make for their children is a purchase

of the pen reader. It is a product for dyslexic, visually impaired, or otherwise handicapped people

that reads written text aloud upon scanning text. It utilizes an Optical Character Recognition

engine implemented in software to take raw input from the scanner at the front of the pen and

cleans it up until it recognizes a character of a certain font. The pen reader then compiles words

and sentences out of these characters and outputs and reads them aloud. It can also read aloud the

meanings of certain words so that the user can understand unfamiliar words. It can also translate

between languages. However, the pen reader's limitations include an inability to read colored text

on colored backgrounds. This can get in the way as a lot of jobs depend on reading text whether

or not it is of a different color, or that it is on a colored background.

Our main objective is to explore the use of different filters and image processing

techniques to improve the pen reader's performance in reading colored text on colored

backgrounds, or to design our own pen reader which would be able to read such text. We also

would like to include a robotic arm to assist in autonomously sorting objects and placing them

where they belong.

## 1. Executive Summary

The problem we would like to address is the inability of the pen reader to recognize

colored text on a colored background. A pen reader is a device that scans lines of text and uses

Optical Character Recognition (OCR) technology [3][8] to recognize words and read them out

loud to the user. Currently, there are no pen readers known to us that can read any text that is not

black on a white background. We will explore the possibility of the creation of a modular

attachment or a modification to the commercially available pen reader that can enable the pen to

read text no matter what the color is, as well as the design of our own pen reader that can take

colored input. We plan to design an electronic filter module using a Raspberry Pi computer to

make colored text input readable to the available software inside the pen. We may have to

include an OCR engine like Tesseract in the Raspberry Pi as we do not yet have the technical

documents of any brand of pen reader to confirm that we can communicate with the pen's

scanner. However, this is just a backup plan. We will also attempt to make modifications to the

sensor at the end of the pen to better receive colored text input and develop an attachment for

that as well. Our solution in the end may use a combination of these, but in the interest of making

the solution modular, we will try our best to use only one.

We will also try to create an autonomous object sorter using a robot arm in conjunction

with the color pen reader to provide a limited degree of automation to simple sorting jobs. In

addition to automating sorting jobs, it will show a handicapped user of the pen exactly how to

use it once the pen is on.

## 2. Opportunity

Our project will help handicapped people by letting them read more text they cannot

otherwise read. Around 5-10%, with some estimates going as far as 17%, of the general

population of the US is dyslexic[1]. Around 3.4 million people in the US are legally blind[2].

There aren't very many things that are written in black text on a white background except for

new books and special labels. Many things, such as product packaging, old yellowed books,

logos, and others have their text stylized in a special font or color or printed on a unique

background. The pen reader on its own is designed to take different fonts into account, but the

problem is that it cannot read color, and so these people have more trouble getting through their

workday than the average worker does. By creating a modular attachment to the pen reader that

allows it to read color, we can lift that barrier to dyslexic, blind, or workers with other reading

disabilities and allow them to work in jobs previously unavailable to them. Any job where you

have to sort things by label or involves other form of text (package sorter, warehouse worker,

etc) is filled with this kind of work. Dyslexic students and researchers would also benefit from

this technology by making it easier to study from old, yellowing books. It will also help those

with disabilities with navigation. There is also an opportunity to reduce the amount of money

spent on special education for dyslexic people, as well as an opportunity to reduce the amount of

stress these workers experience, improving their productivity.

There is also the potential for the robot arm to automate sorting jobs, however this would

require a way for it to autonomously move from place to place to continue sorting, etc. It is safe

to say this project will not replace any jobs at all at this stage. However, if it is expanded upon,

the possibility of automating some unskilled labor is real.

## 3. Proposed Plan of Action

We propose a number of possible solutions. Our main approach to this problem is the

design of an electronic image processor that filters out the raw information from the pen reader's

scanner and transforms it into a form that is acceptable for the pen reader to process. The image

processing will occur on a Raspberry Pi placed in between the pen reader's scanner and

processor.

We can achieve this by first applying a Gaussian filter to the input first to mitigate noise.

After the Gaussian filter stage, we will implement a differential filter (edge detector) in software

in order to sense sharp changes in color and intensity between pixels and create a black and

white image based on that. This will create an outline of the text scanned. This is a form of

image edge detection. We can then further add a post-processor to the system and fill those edges

in with black color so it is easier to process for the pen reader.

Usual methods to detect edges include Canny edge detection [4], image derivative (Sobel

Filter) [5], and phase stretch transform [6]. The first two are available in software libraries like

OpenCV which we also plan to use. The last is not, however with that capability have been

open-sourced. However, we would also like to explore the possibility of using the cosine

similarity method [7] to produce edge detection by putting the color and lightness data of a pixel

into a vector and comparing two adjacent pixels. A value close to 1 indicates similarity, and thus

no change in color, while a value close to 0 indicates difference, and thus a change in color. This

method is not available to implement in OpenCV by default, but is fast and easy to implement.

This method has also been used before, albeit not as commonly as the others mentioned, but it

was stumbled upon independently by the group and has potential.

As a backup plan we can also design our own pen reader based on a camera and a

Raspberry Pi. The Pi's role would stay the same, filtering out color while also having the duty of

processing it and converting the text to speech. Open source OCR engines exist such as Tesseract

and text to speech conversion is not very hard as open source programs exist for that as well, and

we only need to give it proper input and process the output with just an audio amplifier circuit,

such as one based around the LM380.

The robot arm portion of the project will also use a Raspberry Pi to communicate with

our pen reader by Bluetooth. We plan to use Bluetooth communication to send the filtered image

from the scanner so that the robot arm's Raspberry Pi can convert it to text using Tesseract. It

would then use its own control software to approach the object read, using an ultrasonic sensor to

determine distance from the object, then grab it, using tactile pressure sensors to determine when

a good grip has been established, and move it to the place the object belongs to. If the arm senses

resistance to movement (uneven pressure output from the pressure sensors), it assumes the place

is full and seeks out another place to put the object. If all places are full, it places the object back

to its original spot. These sensors mak up the closed-loop control portion of our project.

### 3.1. Project Components

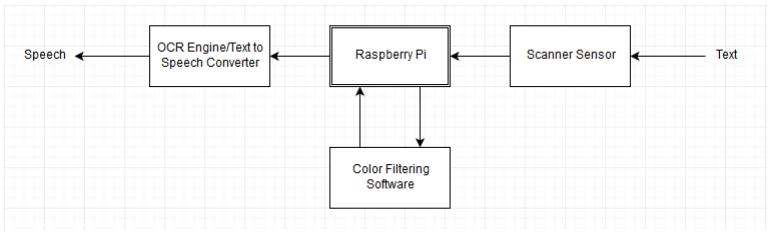
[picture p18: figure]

Figure 1 – General Hardware/Software Diagram of Color Pen Reader

Figure 1 shows the most general workings of our color pen reader project. The scanner

receives text from the page, sends it to our Raspberry Pi, and gets filtered. This goes back out of

the Raspberry Pi and goes to the pen's processing unit to convert to text that is usable by the text

to speech converter. It then outputs the result to a speaker in the pen.

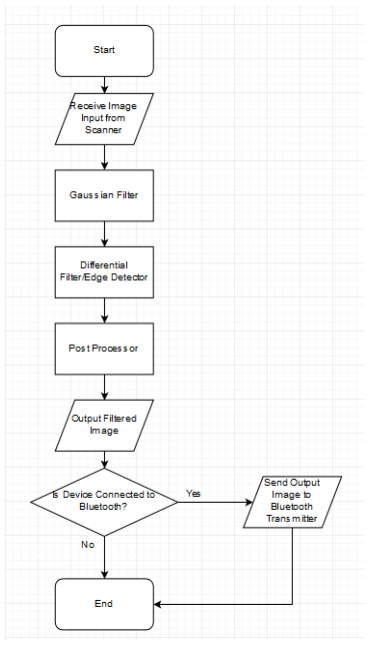
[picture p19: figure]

Figure 2: Color Filtering Software Workflow

Figure 2 shows a description of how the color filtering software works. The Gaussian

filter cleans up noise from the image, which then goes into the edge detector. That output is then

fed into a post-processor which we will add in order to fill in the edges and clean up the eventual

output if the pen reader so requires. The output of the post processor goes back to the Raspberry

Pi to be sent to the pen reader's OCR engine for processing into speech.

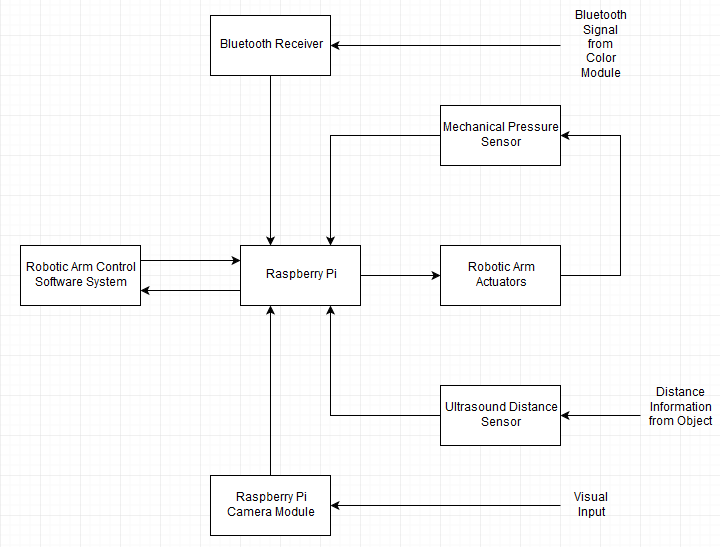
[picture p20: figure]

Figure 3: Robotic Arm Control Diagram

Figure 3 shows the workings of the robotic arm portion of our project. The Control

Software takes in inputs from the pen reader speech, the distance sensor, and the pressure sensor.

Its output is the desired position of the robotic arm. The robotic arm has self-contained control

circuitry embedded into it so that the desired position is maintained. The pressure sensor is a

negative feedback that tells the control software when the robotic arm actuators have a sufficient

grip on the object, while the ultrasonic sensor acts as a negative feedback from the environment

to the control software to tell it when it is close enough to the object so that it can begin the gripping process. This is a closed loop control system where the controller is the robotic arm

control software. Likewise, the pressure sensor can also act as a negative feedback for when the

object that the robotic arm is gripping encounters resistance to movement, as when there is

resistance, there is a mechanical pressure exerted on the object, which exerts mechanical

pressure on the pressure sensors. In this case, we can compare the current pressure with the

pressure felt by the arm from when it first gripped the object, and if it exceeds a certain

threshold, try another spot. If both spots are taken, go back to the original spot and release the

object.

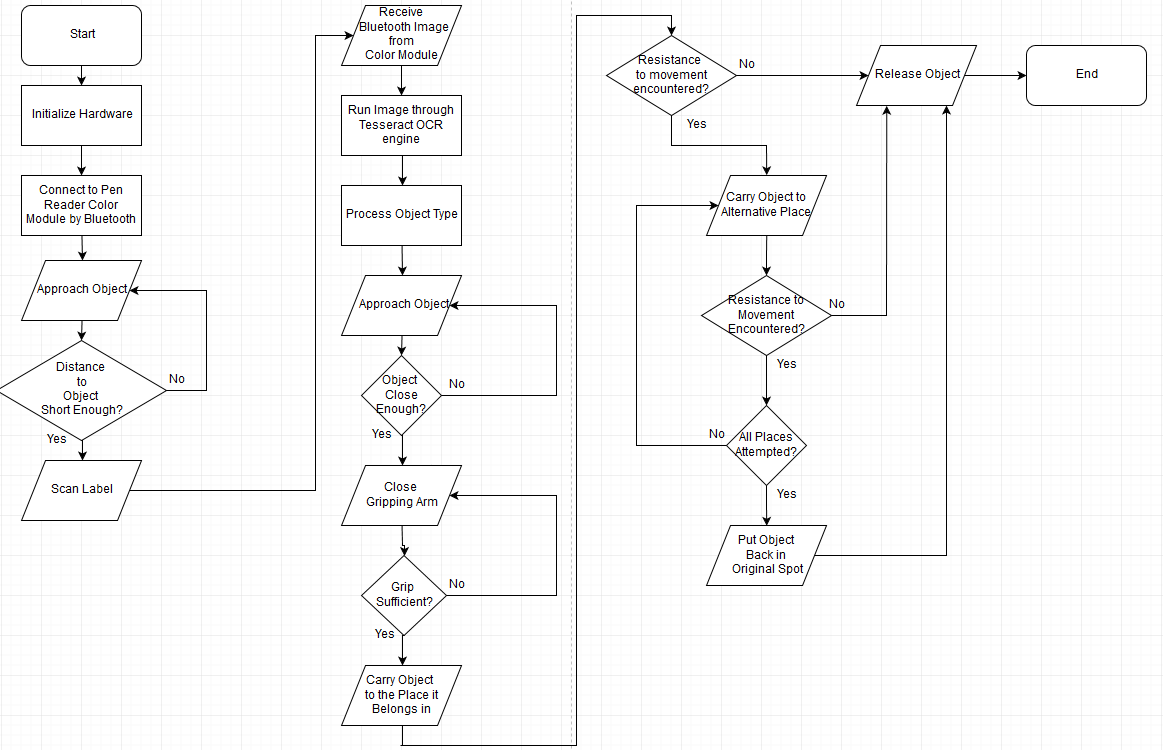
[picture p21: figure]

Figure 4: Robot Arm Control Software Workflow

Figure 4 shows the process of the control of the robotic arm. It first initializes all the

hardware, including connecting to the pen reader via Bluetooth, then approaches the object to be

sorted and scans it, listening for the pen reader’s color module's Bluetooth output. It then puts the

Bluetooth output into an open-source OCR engine like Tesseract and converts the image into

text. From this it figures out the object type and the place it needs to go. Then, it grabs the object,

moving it to the place it belongs in. If there is no space for it, it tries another spot. If all places

are occupied, it puts the object back where it was originally. All along the way it receives

negative feedback from the environment through its sensors and corrects its outputs accordingly

so as not to crash into the object unwittingly or crush it with the gripping arm.

### 3.2. Hardware/software Requirements

1. Raspberry Pi

The Raspberry Pi will serve as the main computing module of our project. It will provide

the processing power to do the image manipulation for the pen reader so it can process

colored input. The Raspberry Pi will also operate the control software used to control the

robot arm and tell it where to go. As such, we will need 2 Raspberry Pis.

2. Pen Reader

We need a pen reader to modify so that we can focus our efforts on providing it with

color reading capability instead of, colloquially put, reinventing the wheel. We will

research how the pen works in detail, as well as how it communicates with the OCR

engine module. Hopefully we can receive technical documents on the pen so we can

expediate this work.

3. Ultrasonic Distance Sensor

This will be used to tell the robot arm how far away it is from the object it is meant to

grip. It helps the Raspberry Pi operate the control software it has on board.

4. Tactile Pressure Sensor

This will provide the Raspberry Pi with tactile feedback so that the control software

knows when to stop increasing its grip on the object. It will also remember the state of the

tactile pressure sensor when it gripped the object originally and compare it with the current state in order to figure out when the object has encountered resistance, signaling

that there is no space in the spot it wanted to put the object in.

5. Raspberry Pi Camera Module

This will be used to have the robot arm see where the pen is. Afterwards it will grip it and

read the label on an object, process it, put the pen down and sort the object accordingly.

6. Raspberry Pi Microphone Module

This will be used to capture sound input from the pen reader's output so that the control

software knows where to place the object.

### 3.3. Simulation Results

Figure 5: Simulated Section of Color Filtering Software

We have written code in Matlab and Python to create simulations of what we plan to use

in the color filtering software of the pen reader. We have implemented the Gaussian filter in our

design simulations and variations of the edge detector filter (Figure 5). So far, we have tested the

cosine similarity, Sobel, and Canny edge detectors, as well as a combination of Sobel and Canny

edge detectors. To thoroughly test each method we wanted to use, we put a low resolution, a

medium resolution, and a high resolution version of the image below through each type of filter

tested in order to draw the most accurate conclusion about each method and what limitations

exist in each method. We created this input in order to test each pure color (red, green, blue) as

well as black and white (Figure 6). We also included a mixed color test with low resolution text

and high resolution text, with both the color of the text and the background chosen at random

(Figure 7). The high resolution picture is 707 x 584. The medium resolution picture is at 355 x

290. The low resolution picture is at 123 x 104. The mixed color input is at 597 x 262.

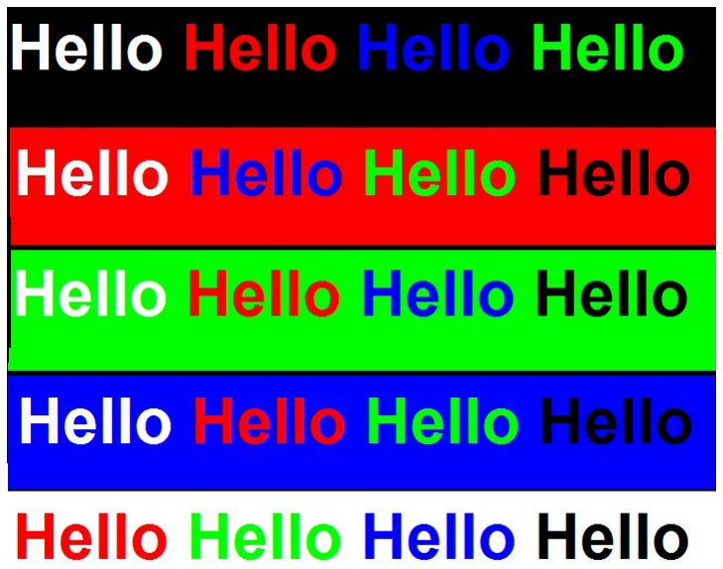
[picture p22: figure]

Figure 6: Pure RGB/BW Test Input

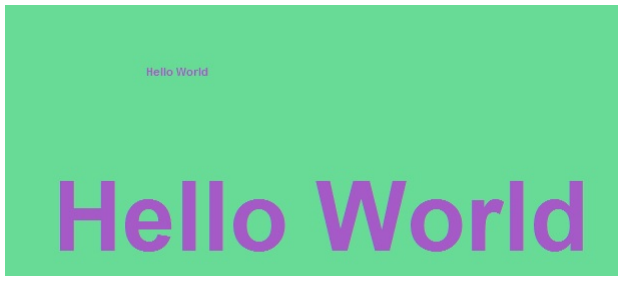
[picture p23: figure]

Figure 7: Mixed Color Test Input

The output of the Canny Filter on a high resolution looked the best (Figure 8, 9).

Moreover, the Canny filter was implemented in Python and used the OpenCV library. Its edges

are sharp and thin, clearly visible, and there are no problems with certain colors. This includes

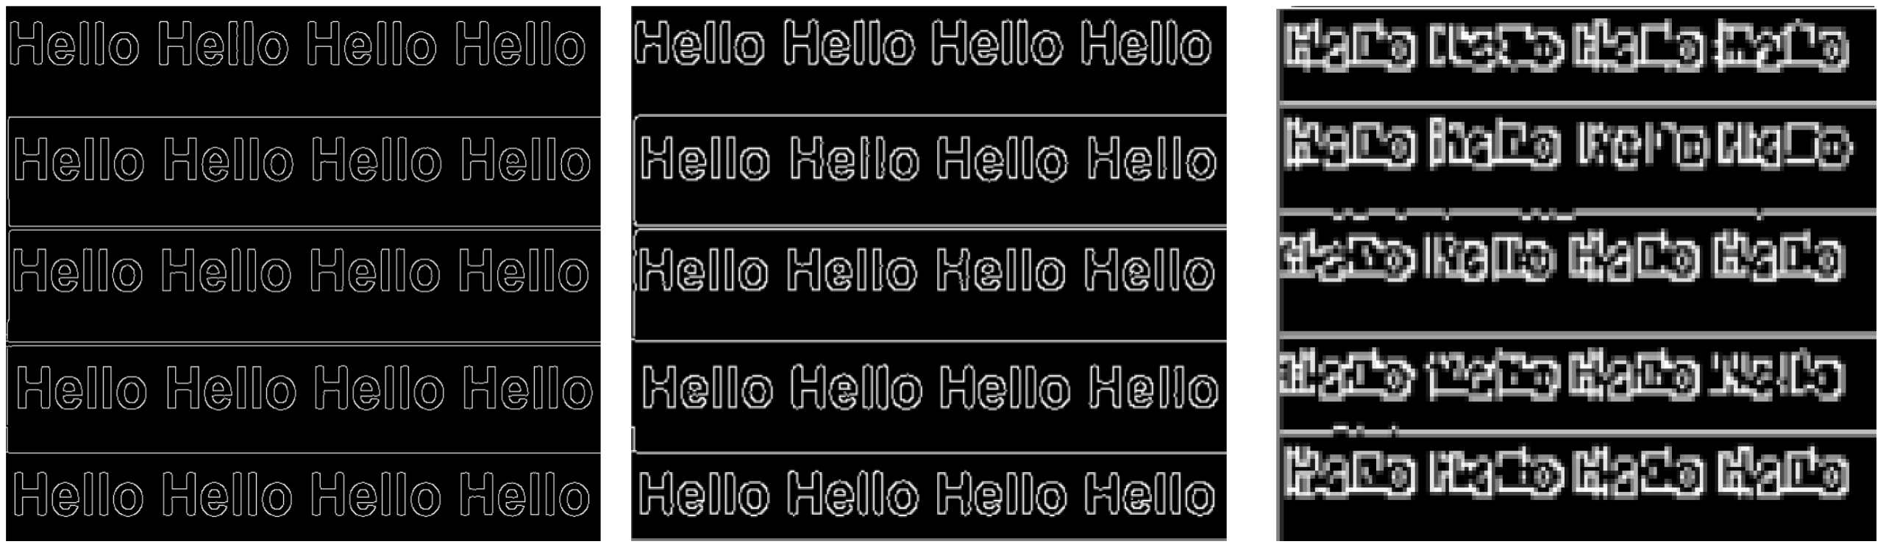
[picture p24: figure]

both outputs from Figure 6 and Figure 7 inputs, however at lower resolutions the output became

more and more noisy and unintelligible.

Figure 8: Pure RGB/BW Canny Detector Output, from highest resolution to lowest


Figure 9: Mixed Color Canny Detector Output

The Sobel Filter was implemented in Matlab. Its output was likewise good, however it

seemed to also be susceptible to unintelligibility at low resolutions (Figure 10, 11). It also

seemed to be sensitive to some colors, with the output being slightly more attenuated than others

seemingly whenever a black color was involved, whether in the text or the background.


Figure 10: Pure RGB/BW Sobel Detector Output, from highest resolution to lowest


Figure 11: Mixed Color Sobel Detector Output

A combination of both the Sobel and Canny detector, implemented using Matlab, led to

some interesting outputs (Figures 12, 13). On one hand, the output was sharp and very defined at

high resolutions. On the other hand, it simply did not work with some color combinations at

medium resolutions and lower, making this method not as flexible as the others we have

simulated. However, it does open up the door to the possibility of trying other combinations,

such as Sobel and cosine similarity or Canny and cosine similarity.


Figure 12: Pure RGB/BW Canny + Sobel Detector Output, from highest resolution to

lowest

Figure 13: Mixed Color Canny + Sobel Detector Output

The cosine similarity detector was also implemented in Matlab. Its output was also not

acceptable at medium resolutions and below, and it had trouble working out the edges of certain

colors and backgrounds (Figures 14, 15). This filter alone is therefore not acceptable for our

purposes.

Figure 14: Pure RGB/BW Cosine Similarity Detector Output, from highest resolution to

lowest


Figure 15: Mixed Color Cosine Similarity Detector Output

The Canny edge detector had the best performance out of all these filters. Its main

advantages over the other methods include a higher resistance to a lowered resolution, as well as

a ready implementation in Python, which is already available on the Raspberry Pi 3 without any

extra effort. However, its limitations include, as with all the other methods, an unintelligible

output at low resolutions. This means we are dependent on the resolution of the scanner sensor of

the pen to be sufficiently high enough in order to be able to use the Canny Edge Detector. If the

scanner sensor is not powerful enough, we may have to replace the scanner sensor of the pen

with a Raspberry Pi 3 Camera Module in order to have the proper resolution. On one hand this

will make the end result more expensive, but on the other hand it will also make the pen reader

modification more modular and potentially easier to develop. This is because we would only

have to translate our output to something the OCR engine of the pen reader understands once. By

using the original scanner sensor, we would have to decode the scanner sensor's output signals

and then re-encode it so the OCR engine can understand it.

Our next steps are simulations with noise added to the image, as well as simulations using

a combination of cosine similarity and Sobel edge detection or cosine similarity and Canny edge

detection. This way we can find more limitations of each method and potentially discover

previously unknown benefits.

## 4. Commercialization

We have to introduce the rational benefit on our improved reading pen. Our tech makes

the reading pen different. When you scan light color characters with darker background, ordinary

reading pens can’t recognize any words at all, which means that handicapped people will have a

harder time reading, and you still have to struggle on looking up words one by one via cell phone

or dictionary. Our project removes the pen reader's color limitation, so you can scan any color of

words conveniently as long as there’s a color difference between characters and the background.

Our project will target people with reading difficulties such as dyslexia, which is a real

time saver to them. Also, those who suffer from the limitation of original reading pens are

willing to see our breakthrough that we remove the color limitation.

We should let customers unconsciously accept the concept of improved reading pen. We

will plan and implement BTL marketing activities which will include free improved pen

experiencing, comparison between the old one and the improved one, distribution of brochures

or banners to introduce feature of our product, scanning QR code to let them feel free to follow

our social media account which helps us to push further notifications. Once their feedbacks are

received through these activities, it will be more efficient to satisfy their needs and leave a good

impression.

We’ll meet a lot of new problems in commercialization. As we all know, there are too

many interconnections between the commercialization and the business operations. However, it

seems that we are neither experienced enough in business operations nor do we have enough

money to commercialize alone. What’s more, our improvement is an integral part of the reading

pen. It would be wise if we can cooperate with a reading pen company as we share mutual

interest. They own the marketing and have more experience in business operations. Also, we can

provide more convenient tech to improve their products, making the cooperation viable. How to

maximize the market acceptance is another thing need to take into consideration. We have to

admit that it’s not an indispensable tool for everyone. It is a specialized product designed for

specific people in mind. It cannot be immediately accessed as a platform like a phone app, which

means that improved reading pen cannot be spread as easily. In order to speed up the formation

of this marketing, we should not only focus on people who have issues on reading but try to create an ambience to people whose English is poor and don’t want to look up words one by one

on cell phones and dictionaries. We must convince them that it would be a better choice to use

our improved reading pen to fix this issue. Through this guidance, they will remember our

product and realize how convenient it is, then gradually accept it.

## 5. Limitations and further Development:

1. OCR technology’s limitation

Optical character recognition technology which is used in our pen has its limitation in

recognizing several parallel character lines. For instance, if the scanner of the pen

includes two lines or one line of characters plus portion of other lines in one scanning,

then the pen cannot recognize two lines or one specific line. We need to improve this

either by restricting the scanning area from outside or improving the algorithm inside the pen. Not only that, but even modern reading pens' success rates range from 81% - 99%

[9].

2. Pen’s limitation

What hardware design the existing pen use in scanning port is same as barcode reader.

The pen emits light to a surface which is scanned by the user, then the pen receives the

reflection of light and process this reflection. We must use a pen that emits only white

light to illuminate the text, otherwise the pen cannot scan colorful materials because

reflection of colored light on same-colored text would be the same color, however if the

background was white, the same color would be reflected too, giving no contrast between

text and background. This means if we want to scan colorful materials, the pen needs to

emit white color which can reflect any color.

3. Recognition algorithm’s limitation

The precision of character recognition algorithm in existing pen is not high. When we use

the pen in scanning some hand-written characters, it cannot recognize them precisely, if

at all.

4. Resource limitation

We haven’t got any technical document of our pen reader yet and we haven’t got the pen

yet either. We cannot ensure that we can add our own design into original pen’s hardware design easily. If we cannot add our own hardware into its original hardware design, then

we need to start the whole pen over and this may need more time, effort, and money.

5. Our scanning module’s limitation

If the contrast between text and background is small, the edge detector output will be

faint. This will make it hard to fill in the edges by the post-processor in the next stage.

We may combine different methods for edge detection and use the output of that, but that

may slow the process down. We must find a good balance between filter quality and

speed.

### 5.1. Impact

1. Our reading pen can help people with dyslexics.

It is estimated that 1 in 10 people have dyslexia [1]. Over 40 million American Adults are

dyslexic - and only 2 million know it. These people cannot read materials as efficient as

people who do not have dyslexia. Our reading pen can help these people solve this

problem because our pen can display, can read in high speed and in high accuracy.

2. Our reading pen can help people who are visually impaired.

Our reading pen can read what it scans so that it can help people who are visually

impaired to understand reading materials. By listening to reading pen, people who have

disability in eyesight can easily understand materials in a normal speed.

3. People who are not familiar with English can also use this pen to help them work.

With our modified algorithm, the reading pen can scan and translate reading materials in

a high speed and high accuracy. Then, people who do not understand English can

understand English as fast as people who are familiar with English.

4. People who have disabilities in arm or hands can also use our reading pen to control

some robotic arms to do some normal action.

Our reading pen has access to our robotic arm. With this robotic arm, people who have

disabilities in arm or hands can easily do some actions which are written in the robotic

arm’s program based on the reading pen’s input. For example, some easy lifting-objects

job can be done by using our reading pen to scan some letters attached on objects, then

one robotic arm can lift that object to another place. With our reading pen and robotic

arm, people who have disabilities in arms or hands can also do jobs like lifting or

carrying.

When our project is successfully finished, it would make life easier for disabled

people, it would improve reading experience and it would make getting jobs easier for

disabled people. Our project also includes one part of controlling robotic arm through the input read into the pen. Then, it also can help people do some specific action like lift

different things depends on what the pen reads.

### 5.2. Prior Art

There are many competing technologies like the C-PEN Reader, ScanMarker and Power

Pen but they don’t read colored text on colored backgrounds well. We will try several algorithms

to solve this problem.

There is no reading pen on the market which uses a robotic arm. Adding this component

will enable the input of the reading pen to produce output, such as when reading pen read letter

like “bottle”, then the robotic arm can lift bottle in one fixed place and then carry the bottle to another fixed place. This is one specific action and robotic arm can potentially do lots of other

things.

## 6. Project Management Plan

### 6.1. Research Plan

Our strategy started with researching on OCR technology. This gave us an insight to what

it’s about and the general uses for it. We then plan on testing the pen we are working with to see

how well it works and how it performs in scanning colored text on colored background.

Choosing our approach will based on several factors such as: size of pen, technical information,

compatibility with filters. We are going to test out increasing the intensity and removing color.

This method is expected to intensify the noise present which could make it harder for the pen to

read, so in order to fix this problem, we plan on applying a Gaussian filter. We also plan using an

additional filter which would mainly be used for sensing color and intensity changes between

each pixels. We will be experimenting with OpenCV to test Canny edge detection and image

derivative, or other libraries in order to test phase stretch transform and cosine similarity. We

will also research a way to implement a post-processor to fill in the edges detected by the

previous filters. In this way the post-processor changes it to a form in which the pen reader can

easily process. We plan to use a Raspberry Pi for this conversion.

We will also use a Raspberry Pi for our robotic arm. It would mainly be used for

communication by voice with our pen reader, so when the pen reader scans a word, the robotic

arm would be expected to pick up the material that was scanned and drop it in a certain position.

### 6.2. Team and Collaboration

Michael Mordkovich (Project Manager/Hardware/Software Engineer)- A very

experienced engineer who has managed several projects, he is well spoken and very

organized. He has also worked with OCR technology and has a clear idea of the direction

in which the project should go. He will be responsible for making sure the project is

delivered on time, within scope and within budget.

Haoran Wu (Hardware / Software Engineer)- Haoran has worked on different projects

which required use of Field – Programmable Gate Arrays (FPGA) and microprocessors.

This experience will be useful in our project.

Ellis Zhu (Software engineer)- he has had a lot of internship experience which has

prepared him for this project. He is a great programmer, very good with Python and

excellent at programming with a Raspberry Pi. He has prior knowledge in modifying

existing codes from OpenCV and writing a code from scratch and is willing to do more

research.

Oluwadarasimi Adeniyi (Project Manager/ Researcher)- Has previous management

experience, led a 5 person team in previous school projects, worked as a general manager

intern, and is also a good researcher and finds useful technical detailed information about

the project. He will be responsible for gathering useful documents, finding reliable

sources and making sure the project is delivered on time.

### 6.3.Milestones and Timeline

Task | Date
Initial Research | 10/07/17 – 12/03/17
AHRC Meeting | 10/24/17 – 10/25/17
Project Proposal Presentation | 11/14/17 – 11/15/17
Budget Acquirement | 11/21/17 – 11/21/17
Pen Reader Acquirement | 11/22/17 – 11/25/17
Decision on Main Approach to Solution | 12/03/17 – 12/25/17

Materials Acquisition | 12/20/17 – 1/17/17
Implement Color Reading Module | 1/17/17 – 3/1/17
Research Scanner to OCR Engine Communication Method | 1/25/17 – 2/3/17
Implement Robotic Arm | 2/3/17 – 3/1/17
Prototype 1 | 2/15/17 – 3/1/17
Prototype Tweaking/Prototype 2 | 3/1/17 – 4/15/17
Final Report | TBA


## 7. Use of Standards

We plan to use the IEEE 802.15.1: WPAN / Bluetooth standard so as to send images

received by the pen reader to the robot arm wirelessly. We chose it because it is used widely for

wireless device-to-device communication.

## 8. Resources and Budget

Item | Unit Price | Units | Purpose | Link
C-Pen Reader | $250 | 1 | This is the Pen Reader we plan on expanding. | https://www.amazon.com/C-pen-C-Pen-Reader/dp/B015 OL7VNS

Raspberry Pi 3 Kit for develop-ment | $69.99 | 1 | It would greatly expediate development if we have a Raspberry Pi dedicated solely as a development platform so that we wouldn't have to swap Pis in and out of our project to try some new code. | https://www.amazon.com/CanaKit -Raspberry-Complete-Starter-Kit/dp/B01C6Q2 GSY
Raspberry Pi 3 for prototype | $35.05 | 2 | One for the Color Reading Module and one for the Robot Arm | https://www.amazon.com/Raspber ry-Pi-RASPBERRYPI 3-MODB-1GB-Model-Motherboard/dp/ B01CD5VC92
Raspberry Pi Camera Module | $28.31 | 1 | This will be used to replace the original scanner sensor of the pen. | https://www.amazon.com/Raspber ry-Pi-Camera-Module-Megapixel/dp/B0 1ER2SKFS/
Lynxmotio n AL5D 4DOF Robotic Arm SSC-32U Combo Kit | $350.80 | 1 | This is the Robot Arm hardware to be controlled by one of our Raspberry Pis. | https://www.robotshop.com/en/lyn xmotion-al5df-kt-robotic-arm-flowbotics-studio.html
IC3D PLA 3D Printer Filament | $29.99 | 1 | We would like to print an enclosure for the Color Reading Module to defend against accidental dropping and other damage. | https://www.amazon.com/IC3D-White-1-75mm-Printer-Filament/dp/B01 1RXNIXO
Turnigy | $14.99 | 2 | This will power the Raspberry Pi on the Color | https://www.ama

7.4 V 1000 mAH LiPo Battery | | | Reading Module as well as the one on the Robot Arm | zon.com/Turnigy -1000mAh-Lipo-HobbyKing-Battery/dp/B007 2AEHIC
Iusun Mini-360 DC-DC Buck Converter Step Down Module | $0.69 | 10 | This is used to step down the voltage of the LiPo battery to a safe voltage that the Raspberry Pis can handle. | https://www.amazon.com/Iusun-Mini-360-Converter-Mini360-4-75V-23V/dp/B074SK 9SSL

Elegoo HC-SR04 Ultrasonic Module Distance Sensor | $11.49 | 1 | This will provide negative feedback to the Robot Arm while it is positioning itself to pick up an object. | https://www.amazon.com/Elegoo-HC-SR04-Ultrasonic-Distance-MEGA2560/dp/B01COSN7O6
Icstation RFP602 500g to 10kg Resistive Thin Film Pressure Sensor Force Sensing Resistor | $10.48 | 2 | This will provide negative feedback to the Robot Arm while it is closing its gripping arm in order keep the arm from crushing the object. It will also sense when the object encounters resistance to movement, signifying that the place the Robot Arm is trying to place the object in is occupied. | https://www.amazon.com/Icstatio n-RFP602-Resistive-Film-Sensor/dp/B06Z YJRN8M
Bluetooth 4.0 USB Module | $11.95 | 2 | This will be used so the Color Module and the Robot Arm Control Software can communicate with each other. | https://www.amazon.com/Bluetoo th-802-15-1-Modules-Dongle-single/dp/B00HK ILG1W
Fluke 113 True-RMS Utility Multimeter | $97.49 | 1 | Multimeter for testing various parts and ensuring the buck converters are set up correctly. | https://www.amazon.com/Fluke-113-True-RMS-Utility-Multimeter/dp/B 01EWFE6XK

Total: $989.91
Note: We have $1000 of funding from AHRC already approved.

## References

[1] Siegel, Linda S. “Perspectives on Dyslexia.”, Paediatrics & Child Health 11.9 (2006):

581–587. Print.

[2] Bailey R. N., Indian R. W., Zhang X., Geiss L. S., Duenas M.R., Saaddine J. B. “Visual

impairment and eye care among older adults—five states,” MMWR 2006; 55(49):1321–1325.

[3] Eikvil, Line. "OCR-Optical Character Recognition.", 1993.
[4] Canny, John. “A Computational Approach to Edge Detection,” IEEE Transactions on

Pattern Analysis and Machine Intelligence, Vol.PAMI-8, No.6, November 1986.

[5] Rebecca Vincent, Folorunso O. “A Descriptive Algorithm for Sobel Edge Detection.”

Proceedings of Informing Science & IT Education Conference (InSITE). 2009.

[6] Mohammad H. Asghari, Bahram Jalali. “Edge Detection in Digital Images Using

Dispersive Phase Stretch Transform.” International Journal of Biomedical Imaging Volume

2015. 2015.

[7] Shweta Atul Page, Kavita J. Mahajan. “Edge Detection Based Classification of

Leukocytes in Blood.” International Journal of Computer Science and Mobile Computing , Vol.

5, Issue. 7,July 2016, pg. 353 – 358. July 2016.

[8] Chentung R. Jih. “Optical Character Recognition Using Baseline Information.”,

US4251799 A, Feb 17, 1981.

[9] Holley, Rose. "How Good Can It Get? Analysing and Improving OCR Accuracy in Large

Scale Historic Newspaper Digitisation Programs", D-Lib Magazine, April 2009.

## Appendix


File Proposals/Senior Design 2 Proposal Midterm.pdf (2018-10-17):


# Autonomous Color Pen Reader

By Team Tao

Oluwadarasimi Adeniyi (Dara)

Haoran Wu (Steven)

Michael Mordkovich (Misha Syrov)

Kaixian Zhu (Ellis)

Faculty Advisor: Dr. Anand Santhanakrishnan

Capstone project proposal submitted in partial fulfillment of

the requirement of the Degree of Bachelors of Science

in the Department of Electrical and Computer Engineering

in the School of Engineering and Computing Sciences

of New York Institute of Technology

Fall 2017

## Table of Contents

## Abstract

Dyslexia affects 5-10% of the general population, with some estimates going up to 17%.

This has a profound effect on productivity of the labor force, as well as creating economic loss as

tens of thousands of dollars are spent by families to accommodate their dyslexic children.

However, even after their formative years, dyslexic people struggle to hold down a job due to

their disability. Furthermore, about 3.4 million people in the US alone are blind.

One of the best investments any dyslexic person can make for their children is a purchase

of the pen reader. It is a product for dyslexic, visually impaired, or otherwise handicapped people

that reads written text aloud upon scanning text. It utilizes an Optical Character Recognition

engine implemented in software to take raw input from the scanner at the front of the pen and

cleans it up until it recognizes a character of a certain font. The pen reader then compiles words

and sentences out of these characters and outputs and reads them aloud. It can also read aloud the

meanings of certain words so that the user can understand unfamiliar words. It can also translate

between languages. However, the pen reader's limitations include an inability to read colored text

on colored backgrounds. This can get in the way as a lot of jobs depend on reading text whether

or not it is of a different color, or that it is on a colored background.

Our main objective is to explore the use of different filters and image processing

techniques to improve the pen reader's performance in reading colored text on colored

backgrounds, or to design our own pen reader which would be able to read such text.

### 1. Executive Summary

The problem we would like to address is the inability of the pen reader to recognize

colored text on a colored background. A pen reader is a device that scans lines of text and uses

Optical Character Recognition (OCR) technology [3][8] to recognize words and read them out

loud to the user. Currently, there are some pen readers with limited color reading ability, but they

fail reliably on certain colors and certain backgrounds due to their limitations. We have explored

the possibility of the creation of a modular attachment or a modification to the commercially

available pen reader that can enable the pen to read text no matter what the color is, and found it

was impossible. Therefore, we are proceeding with the design of our own pen reader that can

take colored input. We plan to design an electronic filter module using a Raspberry Pi computer

to make colored text input readable to available open-source software like Tesseract and festival.

### 2. Opportunity

Our project will help handicapped people by letting them read more text they cannot

otherwise read. Around 5-10%, with some estimates going as far as 17%, of the general

population of the US is dyslexic[1]. Around 3.4 million people in the US are legally blind[2].

There aren't very many things that are written in black text on a white background except for

new books and special labels. Many things, such as product packaging, old yellowed books,

logos, and others have their text stylized in a special font or color or printed on a unique

background. The pen reader on its own is designed to take different fonts into account, but the

problem is that it cannot read color, and so these people have more trouble getting through their

workday than the average worker does. By creating a new pen reader that can filter out color in

text, we can lift that barrier to dyslexic, blind, or workers with other reading disabilities and

allow them to work in jobs previously unavailable to them. Any job where you have to sort

things by label or involves other form of text (package sorter, warehouse worker, etc) is filled

with this kind of work. Dyslexic students and researchers would also benefit from this

technology by making it easier to study from old, yellowing books. It will also help those with

disabilities with navigation. There is also an opportunity to reduce the amount of money spent on

special education for dyslexic people, as well as an opportunity to reduce the amount of stress

these workers experience, improving their productivity.

### 3. Proposed Plan of Action

### 3.1. Project Components

We propose to design a new open-source pen reader with an image processor that filters

out the raw information from the pen reader's scanner and transforms it into a form that is

acceptable for the pen reader to process. The image processing will occur on a Raspberry Pi

while scanning will take place with both a Raspberry Pi and a Trinket M0 microprocessor

working in tandem. We have attempted to create a modular attachment but found it was

impossible after doing more research and contacting the company that manufactures the pen we

have studied. The robotic arm portion of the project has been cancelled due to these changes in

the project requirements.

We can achieve this by first scanning the text with a Raspberry Pi camera and combining

the set of input images. We then apply a Gaussian filter to the input first to mitigate noise. After

the Gaussian filter stage, we will implement a differential filter (edge detector) in software in

order to sense sharp changes in color and intensity between pixels and create a black and white

image based on that. This will create an outline of the text scanned. We have further added a

post-processor to the system that detects letters and detects the kind of letter it is (with no holes

like an L, with one hole like an O, or with two holes like a B) and fills those edges in with black

color so the pen reader is able to process it. Processing of the filtered text is performed by

Tesseract, an open-source OCR engine and the output speech is created by festival, an open-

source text-to-speech converter.

We started with a high level design of the hardware and software and determined the

inputs, outputs, and the requirements of each part in the project. After this, we continued to refine each high-level part into a series of low level requirements and designs. One of the main

components in the open-source pen reader's design is the OCR engine and the text to speech

software. Open-source software exists for both of these – we will use Tesseract for the OCR

engine and festival for the text to speech conversion. Because these components have well-

defined outputs and inputs, and since the output of festival is the only required output of our pen

reader, we have chosen to pursue the refinement of the design backwards; that is, we have

decided to design and implement the pen reader from the output to the input.


Figure 1: High-level Software Design


Figure 2: High-level Hardware Design

The camera is controlled by Raspberry Pi, which listens to two signals isScanning and

CaptureInterrupt sent by microprocessor Trinket M0. When isScanning signal is low, the camera

module is off-work and when isScanning signal is high, the camera will take one photo every

time the captureInterrupt signal’s rising edge comes. The camera will go back to off-work mode

when isScanning signal goes back to low from high and the next stage will execute.


Figure 3: Camera Controller Design

The camera controller depends on feedback from our closed-loop feedback component of

the project. A Trinket M0 in combination with a rotary encoder measures the distance travelled

by the pen reader while scanning text and outputs a captureInterrupt pulse to the Raspberry Pi.

This tells the Raspberry Pi to take a snapshot of what the camera is currently looking at. This is

to keep images evenly spaced so future concatenation will result in the entire text being without

gaps or repetition (from intersecting images). Since it depends on distance travelled, it also lets

the system account for variations in the user's scanning speed. There is a limitation, of course.

Too fast of a scanning speed with result in image blurring and a detrimental effect on the output.

The closed-loop feedback waits until the camera controller module is running so it does not

waste power while the pen reader is processing text. Then, when the Raspberry Pi is ready for

input, it waits until the user holds a button which tells the Raspberry Pi that the user is currently

scanning. It then reads the encoder for changes in position and outputs a captureInterrupt pulse

for the Raspberry Pi to take a picture. When the button is released, it tells the Raspberry Pi that

scanning is finished and the pen reader moves on to concatenate the images and process the

input.


Figure 4: Closed-loop Feedback Design

The image combiner module loads all the images that have been taken by the camera

from one scan and combines them into one single image by concatenating them all.


Figure 5: Image Combiner Design

The color filter component was designed starting from edge detection. Usual methods to

detect edges include Canny edge detection [4], image derivative (Sobel Filter) [5], and phase

stretch transform [6]. The first two are available in software libraries like OpenCV which we also

plan to use. The last is not; however, that capability has been open-sourced. We have also

explored the possibility of using the cosine similarity method [7] to produce edge detection by

putting the color and lightness data of a pixel into a vector and comparing two adjacent pixels. A

value close to 1 indicates similarity, and thus no change in color, while a value close to 0

indicates difference, and thus a change in color. This method is not available to implement in

OpenCV by default, but is fast and easy to implement. This method has also been used before,

albeit not as commonly as the others mentioned, but it was stumbled upon independently by the

group and has potential. After experimentation with MATLAB simulations we have decided that

Canny Edge Detection works best. Our experimentation with Tesseract showed that edge

detection is not enough to reliably read text from images, and that post-processing would need to

be performed. This was included in the color filter module. After the differential filtering is

performed, the color filter binarizes the image and detects separate letters and their type

(specifically, whether the letter has no holes like an L, one hole like an O, or two holes like a B).

After determining the type of letter, it fills in the text accordingly.


Figure 6: Color Filter Design

After processing the input image, it is fed into the Tesseract OCR engine, which converts

the image into text. The output text of Tesseract is then piped into festival which converts it into

sound data. This is sent to the speaker for reading aloud.

### 3.2. Hardware/software Requirements

1. Raspberry Pi 3


Figure 7: Raspberry Pi 3

The Raspberry Pi 3 will serve as the main processing module of our project. It will

receive the feedback from microprocessor Trinket M0 and then control the camera module to

take photos. The Raspberry Pi 3 will also process the photos taken by camera, filter out the color

and send black-and-white image to Tesseract OCR engine and festival text-to-speech software.

2. Microprocessor Trinket M0


Figure 8: Adafruit Trinket M0

This microprocessor Trinket M0 sends two signals isScanning and captureInterrupt to

the Raspberry Pi and it receives the pulse sent by rotary encoder and signal from a button. If the

button is pressed then the Trinket M0 will set the signal isScanning to high and calculate the

distance between position of camera module and the next position of camera module based on

the length of the received pulse’s high level. If the distance reaches a threshold value set in the

code, then the Trinket M0 will set the signal captureInterrupt to high.

3. Raspberry Pi Camera Module


Figure 9: Raspberry Pi Camera Module V2

This camera module V2 uses Sony IMX219 sensor and it’s resolution can reach up to

3280 x 2464 pixels. It will take the pictures of the text to be processed. If processing is slow, the

resolution can be reduced.

4. Rotary Encoder


Figure 10: Signswise 600p/r Incremental Rotary Encoder

We adhere a wheel to its shaft and use it to measure the distance the pen reader has

traveled. When the wheel rolls on the surface of reading materials, the encoder will send out

pulse to microprocessor Trinket M0, then the distance will be calculated and sent to the

Raspberry Pi.

### 4. Commercialization

We have to introduce the rational benefit on our improved reading pen. Our tech makes

the reading pen different. When you scan light color characters with darker background, ordinary

reading pens can’t recognize any words at all, which means that handicapped people will have a

harder time reading, and you still have to struggle on looking up words one by one via cell phone

or dictionary. Our project removes the pen reader's color limitation, so you can scan any color of

words conveniently as long as there’s a color difference between characters and the background.

Our project will target people with reading difficulties such as dyslexia, which is a real

time saver to them. Also, those who suffer from the limitation of original reading pens are

willing to see our breakthrough that we remove the color limitation.

We should let customers unconsciously accept the concept of improved reading pen. We

will plan and implement BTL marketing activities which will include free improved pen

experiencing, comparison between the old one and the improved one, distribution of brochures

or banners to introduce feature of our product, scanning QR code to let them feel free to follow

our social media account which helps us to push further notifications. Once their feedbacks are

received through these activities, it will be more efficient to satisfy their needs and leave a good

impression.

We’ll meet a lot of new problems in commercialization. As we all know, there are too

many interconnections between the commercialization and the business operations. However, it

seems that we are neither experienced enough in business operations nor do we have enough

money to commercialize alone. What’s more, our improvement is an integral part of the reading pen. It would be wise if we can cooperate with a reading pen company as we share mutual

interest. They own the marketing and have more experience in business operations. Also, we can

provide more convenient tech to improve their products, making the cooperation viable. How to

maximize the market acceptance is another thing need to take into consideration. We have to

admit that it’s not an indispensable tool for everyone. It is a specialized product designed for

specific people in mind. It cannot be immediately accessed as a platform like a phone app, which

means that improved reading pen cannot be spread as easily. In order to speed up the formation

of this marketing, we should not only focus on people who have issues on reading but try to

create an ambience to people whose English is poor and don’t want to look up words one by one

on cell phones and dictionaries. We must convince them that it would be a better choice to use

our improved reading pen to fix this issue. Through this guidance, they will remember our

product and realize how convenient it is, then gradually accept it.

Commercialization of the reading pen does not keep it from being open-sourced; instead,

commercialization will help the reading pen become known and will attract more developers to

improve it in the future.

### 5. Limitations and further Development:

1. OCR technology’s limitation

Optical character recognition technology which is used in our pen has its limitation in

recognizing several parallel character lines. For instance, if the scanner of the pen

includes two lines or one line of characters plus portion of other lines in one scanning,

then the pen cannot recognize two lines or one specific line. We need to improve this

either by restricting the scanning area from outside or improving the algorithm inside the

pen. Not only that, but even modern reading pens' success rates range from 81% - 99%

[9].

2. Pen’s limitation

What hardware design the existing pen use in scanning port is same as barcode reader.

The pen emits light to a surface which is scanned by the user, then the pen receives the

reflection of light and process this reflection. We must use a pen that emits only white

light to illuminate the text, otherwise the pen cannot scan colorful materials because

reflection of colored light on same-colored text would be the same color, however if the

background was white, the same color would be reflected too, giving no contrast between

text and background. This means if we want to scan colorful materials, the pen needs to

emit white color which can reflect any color.

3. Recognition algorithm’s limitation

The precision of character recognition algorithm in existing pen is not very high. When

we use the pen in scanning some hand-written characters or noisy text, it cannot

recognize them precisely, if at all.

4. Our scanning module’s limitation

If the contrast between text and background is small, the edge detector output will be

faint. This will make it hard to fill in the edges by the post-processor in the next stage. We

may combine different methods for edge detection and use the output of that, but that

may slow the process down. We must find a good balance between filter quality and

speed.

### 5.1. Impact

1. Our reading pen can help people with dyslexics.

It is estimated that 1 in 10 people have dyslexia [1]. Over 40 million American Adults are

dyslexic - and only 2 million know it. These people cannot read materials as efficient as

people who do not have dyslexia. Our reading pen can help these people solve this

problem because our pen can display, can read in high speed and in high accuracy.

2. Our reading pen can help people who are visually impaired.

Our reading pen can read what it scans so that it can help people who are visually

impaired to understand reading materials. By listening to reading pen, people who have

disability in eyesight can easily understand materials in a normal speed.

3. People who are not familiar with English can also use this pen to help them work.

With our modified algorithm, the reading pen can scan and translate reading materials in

a high speed and high accuracy. Then, people who do not understand English can

understand English as fast as people who are familiar with English.

When our project is successfully finished, it would make life easier for disabled

people, it would improve reading experience and it would make getting jobs easier for

disabled people.

### 5.2. Prior Art

There are many competing technologies like the C-PEN Reader, ScanMarker and Power

Pen but they don’t read colored text on colored backgrounds well. We will try several algorithms

to solve this problem.

Open-source software for OCR such as Tesseract (and others) exist and are freely avail-

able. Of open-source technologies, Tesseract is the most accurate and will be used for our pur-

poses. Proprietary OCR engines offer higher accuracy in reading text from images, but are not

available to us due to our goal to make the pen reader open-source.

Festival is an open-source software tool for converting text to sound data. It is one of the

best available in terms of voice clarity. We will also use this to develop our project.

### 6. Project Management Plan

### 6.1. Future Plan

Between now and the 10th of May, we shall continue development as follows: In week 1

we shall finish all the software required for the camera controller and the feedback. In week 2 we

will design and assemble a simple 3D printed enclosure for the scanner. In week 3 we will

present what we have at the CREATE symposium and finish the tweaks in the feedback system

such that the camera will take pictures spaced evenly and accurately so as to be able to combine

them into one line of text. In week 4 we will add a battery, a speaker, tweak anything that needs

tweaking, fix any bugs that we find during testing, and present our final prototype for the color

pen reader.

We would also like to include a setup script that can automatically install the pen reader

software for ease of use for non-technical people. This design will be uploaded to Github so that

future developers may contribute to it.

Further development is possible by replacing the Raspberry Pi 3 hardware with a

Raspberry Pi Zero for size minimization, so that the pen reader can possibly fit into a single

enclosure for comfort of use.

### 6.2. Team and Collaboration

Michael Mordkovich (Project Manager/Hardware/Software Engineer)- A very

experienced engineer who has managed several projects, he is well spoken and very

organized. He has also worked with OCR technology and has a clear idea of the direction

in which the project should go. He will be responsible for making sure the project is

delivered on time, within scope and within budget.

Haoran Wu (Hardware / Software Engineer)- Haoran has worked on different projects

which required use of Field – Programmable Gate Arrays (FPGA) and microprocessors.

This experience will be useful in our project.

Ellis Zhu (Software engineer)- He has had a lot of internship experience which has

prepared him for this project. He is a great programmer, very good with Python and

excellent at programming with a Raspberry Pi. He has prior knowledge in modifying

existing codes from OpenCV and writing a code from scratch and is willing to do more

research.

Oluwadarasimi Adeniyi (Project Manager/ Researcher)- Has previous management

experience, led a 5 person team in previous school projects, worked as a general manager

intern, and is also a good researcher and finds useful technical detailed information about

the project. He will be responsible for gathering useful documents, finding reliable

sources and making sure the project is delivered on time.

### 6.3. Milestones and Timeline

Task | Date
Initial Research | 10/07/17 – 12/03/17
AHRC Meeting | 10/24/17 – 10/25/17
Project Proposal Presentation | 11/14/17 – 11/15/17
Budget Acquirement | 11/21/17 – 11/21/17
Pen Reader Acquirement | 11/22/17 – 11/25/17
Decision on Main Approach to Solution | 12/03/17 – 12/25/17
Materials Acquisition | 12/20/17 – 1/17/18
Implement Color Filter | 1/17/18 – 3/1/18
Implement Image Combiner | 1/25/18 – 2/3/18
Prototype 1 | 4/3/18
Prototype Tweaking/Prototype 2 | 4/3/18 – 5/10/18
Final Report | 5/10/18


Figure 11: Development Schedule
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

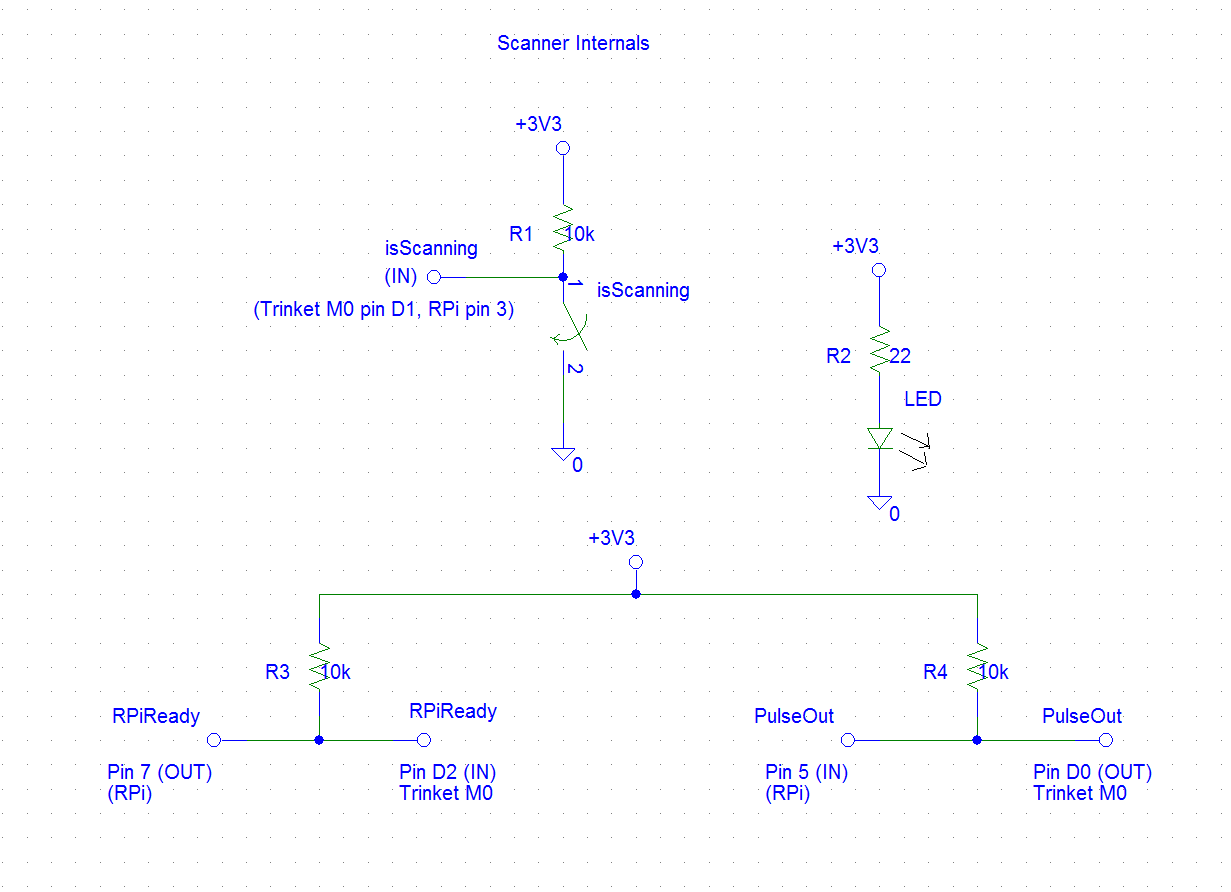
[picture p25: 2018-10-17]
Pictures/Scanner Internals.png

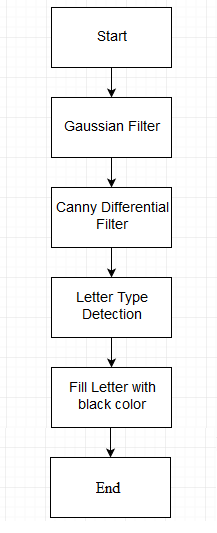
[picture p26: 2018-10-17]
Pictures/color filter logic.png

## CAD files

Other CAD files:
3D Print Files/Final Prototype/tao v1.f3d
3D Print Files/Final Prototype/wheel v1.f3d
3D Print Files/Prototype 1/camera handle TAO part1 v1.f3d
3D Print Files/Prototype 1/camera handle TAO part2 v2.f3d

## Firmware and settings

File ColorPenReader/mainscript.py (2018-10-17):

# import stuff
import subprocess
import imagestitch
import Cfilter
import cameracontroller

while True:
    # run camera controller
    cameracontroller.runCamera()
    # run image concatenation
    imagestitch.mainCombineImages()
    # run color filter
    Cfilter.filterColor('/home/pi/Desktop/ColorPenReader/stitched_image.jpg')
    # run OCR and pipe output to TTS
    p2 = subprocess.Popen(["tesseract", "/home/pi/Desktop/ColorPenReader/readyImage.png", "stdout"], stdout=subprocess.PIPE)
    p3 = subprocess.Popen(["festival", "--tts"], stdin=p2.stdout)

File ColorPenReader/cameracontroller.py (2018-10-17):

import picamera
import RPi.GPIO as GPIO
import shutil
import os
import time

photo_num = 0

def runCamera():
    #set up camera
    camera = picamera.PiCamera(framerate=90, sensor_mode=7)
    camera.resolution = (640, 480)
    camera.start_preview()

    #set up callback method
    def captureImage(channel):
        global photo_num
        camera.capture('rawImages/' + str(photo_num) + '.jpg')
        photo_num += 1

    #Pin numbering
    IS_SCANNING = 3
    CAPTURE_INTERRUPT = 5
    RPI_READY = 7

    #IO setup
    GPIO.setmode(GPIO.BOARD)
    GPIO.setup(IS_SCANNING, GPIO.IN, pull_up_down=GPIO.PUD_UP)
    GPIO.setup(CAPTURE_INTERRUPT, GPIO.IN, pull_up_down=GPIO.PUD_UP)
    GPIO.setup(RPI_READY, GPIO.OUT)

    #delete the rawImages folder and recreate it
    shutil.rmtree('/home/pi/Desktop/ColorPenReader/rawImages')
    os.mkdir('rawImages')

    #get ready for scanning
    GPIO.output(RPI_READY, True)

    #when isScanning is low, waiting for isScanning goes to high
    while GPIO.input(IS_SCANNING) == True:
        pass

    #when isScanning is high, call captureImage() whenever CaptureInterrupt rising edge is detected
    if GPIO.input(IS_SCANNING) == False:    
        GPIO.add_event_detect(CAPTURE_INTERRUPT, GPIO.RISING, callback=captureImage, bouncetime=100)
        time.sleep(0.01)
        while GPIO.input(IS_SCANNING) == False:
            pass    

    camera.stop_preview()
    time.sleep(1)
    camera.close()
    GPIO.cleanup()
